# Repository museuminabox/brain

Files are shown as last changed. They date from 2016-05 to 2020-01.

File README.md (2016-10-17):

# brain

You're probably looking for https://github.com/museuminabox/brain/blob/master/INSTALL.md.

When you get your Museum in a Box, the box knows which objects are in it and can tell you things about them. That's because of The Brain, a microcomputer like a Raspberry Pi. There are a few peripherals too, like an RFID reader, speakers, and a screen. The brain also keeps a note of any time an object comes across it. This is called the BOOP LOG.

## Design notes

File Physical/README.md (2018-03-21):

# Physical Details of the Brain

This folder holds things relating to the physical instantiation of the Brain (rather than the software installed on it).

That includes things like the design files for laser-cut enclosures, and design files for [any custom PCB](BootProgressBoard/).

## Wiring

These wiring details use [this Raspberry Pi GPIO connector diagram](http://elinux.org/RPi_Low-level_peripherals#Model_A.2B.2C_B.2B_and_B2) for labels.

### RFID Reader

|Connector P1 (l-r)|Raspberry Pi|
|---|---|
|VCC|+3V3|
|IN|Not connected|
|SDA|GPIO2/SDA1|
|SCL|GPIO3/SCL1|
|OUT|GPIO4|
|GND|GND|

### BootProgressBoard

|Connector P1 (l-r)|Raspberry Pi|
|---|---|
|1|GPIO24|
|2|GPIO25|
|3|GPIO17|
|4|GPIO27|
|5|GPIO22|
|6|GPIO23|
|7|GPIO10|
|8|+3V3|
|9|GND|

### Raspberry Pi 2/3

Audio is provided by an amplifier board connected to the 3.5mm jack on the Pi.

See [here for a diagram showing the 3.5mm connections](http://www.raspberrypi-spy.co.uk/2014/07/raspberry-pi-model-b-3-5mm-audiovideo-jack/)

|Amp|3.5mm jack on the Pi|
|---|---|
|Left|Tip|
|Right|Ring 1|
|Ground|Ring 2|
|Not connected|Sleeve|

### Raspberry Pi Zero

Audio is provided by a DAC board.  Either the [Pimoroni pHat DAC](https://shop.pimoroni.com/products/phat-dac) with stackable headers; or the [Adafruit I2S DAC/Amp board](https://learn.adafruit.com/adafruit-max98357-i2s-class-d-mono-amp/overview).

For the DAC/Amp the connections are as follows:

|DAC/Amp board|Raspberry Pi|
|---|---|
|LRC|GPIO19/MISO|
|BCLK|GPIO18|
|DIN|SCLK/GPIO21|
|GAIN|Not connected|
|SD|Not connected|
|GND|GND|
|Vin|+5V|

Because the DACs don't have volume controls, we add two buttons for volume up and down.  They're connected as follows (l-r in [this photo](https://www.flickr.com/photos/amcewen/31221595945/)):

|Volume board|Raspberry Pi|
|---|---|
|Volume up|GPIO6|
|Volume down|GPIO13|
|Ground|GND|
|Pin with neither button but both resistors|Not connected|

## Assembly

This isn't necessarily the *only* way to assemble the Brain, but the general order that we've taken.

### Assemble "base of the skull"

1. Assemble an [audio circuit](#Wiring_the_audio_circuit)
1. Assemble an amp-to-speaker wiring loom
1. Carefully bend the terminals on the speaker so that they form a right-angle
1. Test assemble the speaker frame and then glue it together with the speaker inside
1. Plug in the 3.5mm audio jack to connect the audio circuit to the Raspberry Pi
1. Fit the rivets into the base first
1. Push Raspberry Pi down onto the rivets in the base

### Assemble "top of the skull"

1. Lay out all the components to check that you've got everything.
1. Insert the 4 t-nuts into the base of the top
1. Solder the right-angle header onto the RFID reader
1. Test assemble the RFID reader frame, and then glue together
1. Check the fit for the pieces making up the main box
1. Glue together the pieces for the main box, apart from the top
1. Once the main box is dry, glue in the top
1. Sand down the box (if it's not acrylic)
1. Apply one or two coats of Danish oil to the box (similarly if it's not acrylic)

### Wiring the Boot Progress PCB

1. Solder up the Boot Progress Board PCB

### Wiring the audio circuit

1. For the analogue amplifier Brains, solder header pins into the amplifier
1. We use pre-assembled [cables connected to a TRRS 4-pole 3.5mm jack plug](http://uk.farnell.com/cliff-electronic-components/fc68122c/cable-assembly-jack-plug-4-way/dp/2470995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) to connect to the Pi, so check that which wire colour goes to which pole on the plug.  If you're soldering your own wires to a 3.5mm plug, then obviously you'll know which is which.  In our case the colour-coding is:
  * Tip: red
  * Ring 1: white
  * Ring 2: black
  * Sleeve: shielding
  Or for the double-ended cables we're using in v1, the colour-coding is:
  * Tip: red
  * Ring 1: white
  * Ring 2: green
  * Sleeve: blue or black
1. Assuming you're using the same [3.5mm switched audio jack](http://www.digikey.co.uk/product-detail/en/cui-inc/SJ1-3535/CP1-3535-ND/738693) as we do, then connect the following connections to wire the 4-pole TRRS plug to the aux audio jack:
  * Tip (red) to connection 2
  * Ring 1 (white) to connection 3
  * Ring 2 (black/green) to connection 1
  * Sleeve is left unconnected
1. If you're using the same amplifier board as us, you should desolder the audio jack from it.  When you have, the connections&mdash;when viewed from underneath, from left to right&mdash;are tip \ sleeve / ring (on a TRS stereo jack)
1. Wire the output connections of the aux jack to the amplifier, with ~20cm of cable.  We'll leave the ground connection unconnected as it will prevent a ground loop with the ground connection for power.
  * Connection 4 (red) to the left audio input
  * Connection 5 (white) to the right audio input

### Prep the amp-to-speaker wiring loom

1. Cut a 15cm length of 2-core cable
1. Bare ~5mm of wire at one end and tin the end
1. Bare ~10mm of wire at the other end
1. Insert the longer bared ends through the loops on the terminals on the speaker (if you've got coloured wire, red to positive and black to negative) then fold it back on itself to make a decent physical connection.  Then solder the wires to the speaker terminal

### Assemble main wiring loom

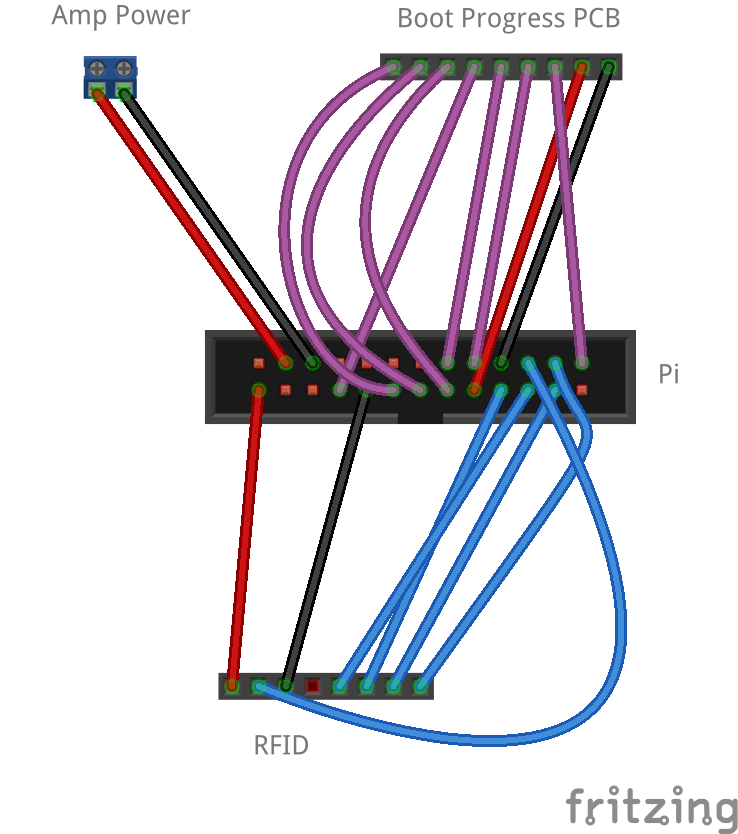
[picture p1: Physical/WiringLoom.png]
Image of wiring loom


1. Get the RFID to Pi connector cable
1. Wire a two-pin shroud to the 5V and ground connection on the RFID reader shroud to break out power from the Raspberry Pi to the amplifier
1. Assemble the Boot Progress PCB wiring loom with 9-pin shroud and [connections as detailed above](#BootProgressBoard)

### Assembly
1. Fasten the USB extension cable into the main box
1. Connect up all the electronics and make sure it's all working before it gets installed fully
1. Fit the amp and 3.5mm jack socket into the main box
1. Hot-glue the boot progress board into the main box

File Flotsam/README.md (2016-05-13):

# Flotsam

Handy bits and pieces that aren't crucial to the Brain or its operation, but are handy to have stashed away in source control.

## Files

 * [DisplayCard.docx](DisplayCard.docx) - a simple "what is this?" card to position next to the Museum in a Box if it's on display unattended somewhere.  Like the sort of thing that's next to an exhibit in a museum.  Works remarkably well just laser-printed and spray mounted to a piece of white foamcore.
 * [TagSizeTemplates.svg](TagSizeTemplates.svg) - laser-cutter outline file to cut a variety of common NFC tag sizes, so you can check them against prints to see what fits before you buy tags.

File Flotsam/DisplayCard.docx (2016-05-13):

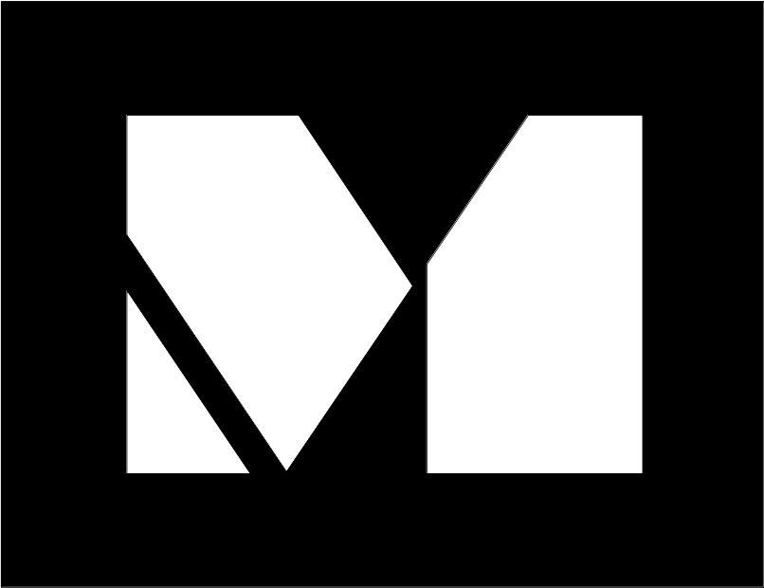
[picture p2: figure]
Created with Sketch.

Museum in a Box

http://www.museuminabox.org

3D scanned and 3D printed objects from museums, with some smarts inside.

Place an object onto the “brain” box to learn more...

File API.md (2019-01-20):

# Cloud API

These are the calls the box expects to be able to call in the cloud service, in order to administer the box.

Previously the paths did not start with `/api/`. The old URLs should now redirect to the new paths that do start with `/api/`.

## Record Boop Start

POST https://museuminabox.herokuapp.com/api/boopstart at the start of the Boop

NO LONGER WORKING: POST https://museuminabox.herokuapp.com/boops This is the old pre-v1 API to record (the start of) a Boop

### Submits

Example of a Boop submission currently:

JSON:
```
{ 
  "created_at": "2018-02-26T14:46:15.704Z", 
  "box_id": 64, 
  "print_id": "347"
}
```

 Yes, "print_id" appears to be sent as a string, so to support this, both IDs can be sent as integers or strings.
 
`box_id` can also be a Box's UUID - this should be the standard in the future. e.g.:

```
{ 
  "created_at": "2018-02-26T14:46:15.704Z", 
  "box_id": "1277209b-7e87-4023-a852-617e79ae6b18", 
  "print_id": "347"
}
```

### Success response

200 status code.

Returns the ID of the Boop that was created.

```
{
  "boop_id": 12345
}
```

### Error reponse 

400 status code (for example).

JSON returned will be like:

```
{
  "success": false,
  "errors": [
    "Something went wrong",
    "And here's another error message"
  ]
}
```

## Record Boop End

POST https://museuminabox.herokuapp.com/api/boopend at the end of the Boop

### Submits

JSON:
```
{ 
  "created_at": "2018-02-26T14:46:15.704Z", 
  "boop_id": 12345
}
```

### Success response

200 status code.

Returns the ID of the Boop that was updated.

```
{
  "boop_id": 12345
}
```

### Error reponse

400 status code (for example).

JSON returned will be like:

```
{
  "success": false,
  "errors": [
    "Something went wrong",
    "And here's another error message"
  ]
}
```

## Create box by UUID

POST http://museuminabox.herokuapp.com/api/boxes.json

### Submits

* UUID for the box to be created, as parameter `id`.
* The Hardware ID, as entered by the user. A string as parameter `hardware_id`.
* The box's exterior description. A string as parameter `exterior`.

### Success response

200 status code.

JSON of box details for the newly created box, as would be returned by the Retrieve box details API.

### Error response

400 status code (for example).

JSON returned will be like:

```
{
  "success": false,
  "errors": [
    "Something went wrong",
    "And here's another error message"
  ]
}
```
 
## Retrieve box details

GET http://museuminabox.herokuapp.com/api/boxes/:box_id.json

`box_id` can be the Box's database ID or its UUID (for newer boxes).

The JSON response will be something like:

```
{
  "id": "8e12b719-3c76-4a6a-9465-1087697acc61",
  "hardware_id": "0001",
  "exterior": "Shiny yellow plastic",
  "created_at": "2018-02-22T12:00:00Z",
  "updated_at": "2018-02-22T12:00:00Z",
  "brain_type": "audio",
  "private": True
}
```

## Synchronize box information for a given box

POST http://museuminabox.herokuapp.com/api/boxes/:box_uuid/sync.json
 
### Submits

JSON:
```
{ 
  "software_version": "0.9.0", 
}
```

### Success response

200 status code.

JSON:
```
{
  "prints": [
    {
      "id": 12,
      "name": "thing_name",
      "collection_id": 11,
      "collection_name": "Ancient Egypt: Daily Lives"
      "url": "https://museuminabox.herokuapp.com/boxes/12/",
      "brain_type": "audio",
      "image_url": "https://museuminabox.s3.amazonaws.com/prints/images/95e5e0bd-a724-4ba2-8004-a2abb92896a5.jpg",
      "brain_filename_audio": "b1bd2c2c-ce86-4360-a195-60a40353ac72.wav",
      "brain_url_audio": "https://museuminabox.s3.amazonaws.com/prints/audio/b1bd2c2c-ce86-4360-a195-60a40353ac72.wav"
     },
     {
      "id": "8e12b719-3c76-4a6a-9465-1087697acc61",
      "name": "thing_name",
      "collection_id": 110,
      "collection_name": "Barnsley Museums - Collections 1-6"
      "url": "https://museuminabox.herokuapp.com/boxes/34/",
      "brain_type": "audio",
      "image_url": "https://museuminabox.s3.amazonaws.com/prints/images/95e5e0bd-a724-4ba2-8004-a2abb92896a5.jpg",
      "brain_filename_audio": "b1bd2c2c-ce86-4360-a195-60a40353ac72.wav",
      "brain_url_audio": "https://museuminabox.s3.amazonaws.com/prints/audio/b1bd2c2c-ce86-4360-a195-60a40353ac72.wav"
    },
  ]
}
```

## Retrieve list of available boxes

DEPRECATED.  Used in the initial brain bootstrapping workflow, now superseded by the Create Box by UUID workflow.

GET http://museuminabox.herokuapp.com/api/boxes.json

### Returned

JSON:
```
[
  {
    "id": box_id, 
    "hardware_id": "The box hardware ID",
    "url": box_details_url,
    "name": "Name of the Box",
    "brain_type": "audio"  // LEGACY, used to be either "audio" or "video", currently "audio" is the only type supported
  },
  ...
]
```

`box_id` will be a UUID for boxes that have them, otherwise the internal numeric database ID.

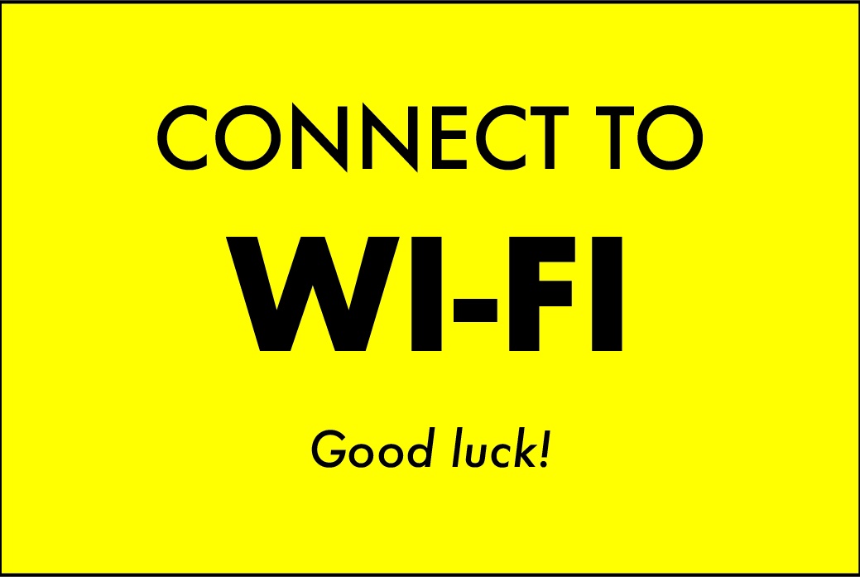
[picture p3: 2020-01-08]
miab/web-static/wifi-card.jpg

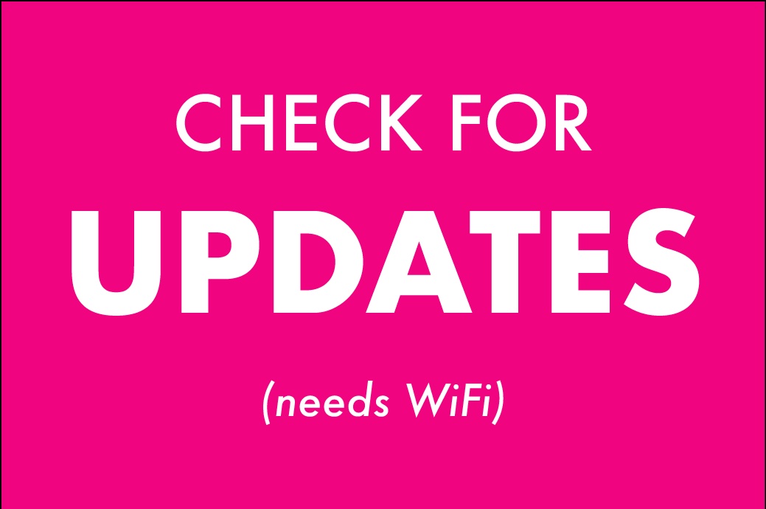
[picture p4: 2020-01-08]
miab/web-static/update-card.jpg

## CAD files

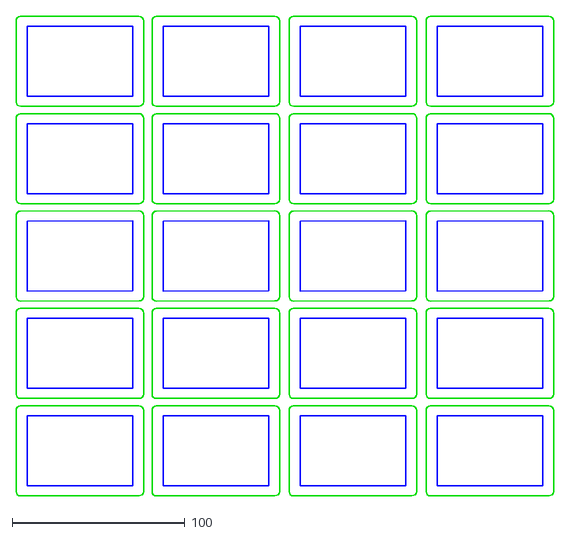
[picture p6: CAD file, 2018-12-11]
Physical/skull_20_reader_spacers.dxf
311.2 x 277.6

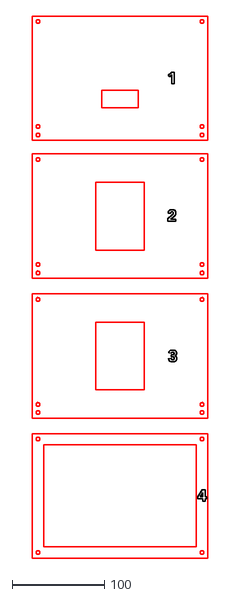
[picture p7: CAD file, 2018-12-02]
Physical/rfid_positioning_jig.dxf
190.0 x 587.8

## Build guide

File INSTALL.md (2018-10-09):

# Building a Brain

## Prerequisites

1. Raspberry Pi 2
1. SL030 RFID reader
1. SL030 to Raspberry Pi interconnect cable
1. Power supply
1. Speakers
1. Micro-SD card (8GB or higher recommended)
1. HDMI screen (for video version)
1. WiFi dongle (optional)

## Assembly

1. Attractively arrange componentry on a table - _this requires considerably more information :)_
1. Place micro-SD card into Raspberry Pi
1. Put WiFi dongle into one of the USB ports on the Raspberry Pi
1. Connect the short (6-way) end of the Pi-to-SL030 interconnect cable to the SL030 RFID reader.  The red wire should connect to the pin marked Vcc and the black wire should connect to the pin marked GND.
1. Connect the long end of the Pi-to-SL030 interconnect cable to the headers on the Raspberry Pi.  The wires should be in the "bottom left" of the headers if the Raspberry Pi logo printed on the Pi is the correct way round.
1. (Optional) Connect the HDMI cable if this is a video brain.
1. Connect the power to the Pi.

## Installation

### Manual Install

1. Install latest Raspbian
1. Install Node RED (if it wasn't already on the Raspbian image)
1. Install rfid-sl030 and ndef node.js modules
1. Copy contents of [miab](miab) to /home/pi
1. Copy flows_brain.json to /root/.node-red/ (you will need to rename it to flows_<hostname>.json depending on the hostname of your Pi)
1. Install [simple_sl030_rfid_reader]() and build `get_first_ndef_text_record` for it
1. Copy `bootprogress` to `/etc/init.d` to indicate progress during boot-up
1. Set `bootprogress` to run - `sudo update-rc.d bootprogress defaults`

### Ansible Install

1. Install [Ansible](https://www.ansible.com/get-started) on your computer
1. Install the latest [Raspbian lite image](https://www.raspberrypi.org/downloads/raspbian/) onto a micro-SD card
1. Create a file called `ssh` on the `/boot` partition of the SD card.  The contents don't matter, it's just to enable the SSH server.  E.g. on Ubuntu `touch /media/myusername/boot/ssh`
1. Boot the Raspberry Pi with the micro-SD card, while plugged into a network via Ethernet
1. Find out the IP address of the Raspberry Pi
1. Copy your SSH credentials onto the Pi
  ```ssh-copy-id pi@<ip-address-of-the-pi>```
1. Edit the ```hosts``` file so ansible knows which computer to configure.  Change the IP address in it to match the one you just found out.
1. Check you can run commands on the Pi using Ansible
   ```ansible brain -i hosts -a "hostname" -u pi```
1. Create a password for the `pi` user
   ```mkpasswd --method=sha-512 > pwd.txt```
1. Update the brain
   ```ansible-playbook brain.yml -e pi_password=`cat pwd.txt` -i hosts```

### Pre-rolled Image Install

Or use the pre-rolled images...

1. Download one of our image files
1. Unzip it, so you end up with a brain-YYYYMMDD.img file
1. Write the .img file to the SD card, following the steps on the Raspberry Pi website - [Mac](https://www.raspberrypi.org/documentation/installation/installing-images/mac.md)/[Windows](https://www.raspberrypi.org/documentation/installation/installing-images/windows.md)/[Linux](https://www.raspberrypi.org/documentation/installation/installing-images/linux.md)
1. Put the SD card into the Raspberry Pi on the Brain and boot it up
1. Visit [http://box.local:1880/setup](http://box.local:1880/setup) to configure the brain

## Connecting to WiFi

To add new WiFi network credentials to the brain you will need a working network connection to the brain already.  So either add the settings before you move it from a known WiFi setup, or connect it to the network via Ethernet first.

 1. Get a command line connection to the brain ssh pi@brain-1.local
    - turn on pi, plug ethernet
    - (optional, for direct to laptop) share wifi via ethernet, set IP Add. to 10.0.0.1, make sure wifi is connected!
    - in terminal, type ssh pi@brain-1.local (or pi@brain-2..., or pi@brain-3...)
    - enter password for brain
 1. Run the WiFi config console
     sudo wicd-curses
 1. Find the network that you want to configure on the list.  Press the -> key to move to the configuration screen.  Use the down cursor key to find the "Automatically connect to this network" setting, then press the space bar to enable it "[X]" rather than "[ ]".  If the network requires encryption then cursor down to the "Key:" field and fill in the password there.
 1. Hit "F10" to save the settings.
 1. Type "Q" to quit from the WiFi config app.
 1. Next time you boot up, it should choose the newly configured WiFi.  (You'll need to unplug the Ethernet if you've used that, otherwise it'll use that in preference)

## Writing new tags

### Writing the metadata to the tags
1. Get the system up and running
1. Using an NFC-enabled phone, write a URL to the tag you want to write. (It will be overwritten, and this step will be removed when we work out how to format blank tags)
1. Place the tag onto the reader
1. In a browser, go to http://brain-1.local:1880/tag (depending on which brain you're connecting to, it might be brain-2.local instead)
1. Fill in the details
  * URL is the link to the print on the website (this is where a Phone will visit when you tap the tag on it)
  * ID is the print's ID in the database (the number at the end of the URL)
  * The filenames are the names of the media files that you'll copy onto the Brain in a minute
1. Click write

### Copying content over to the Brain
1. Open the "transmit" app (on Mac)
1. Create a new favourite, with the server of box.local, protocol set to "SFTP" username pi, password raspberry
1. Connect to it, copy the audio and video files into the respective miab/audio and miab/video folders
1. Repeat the process for all the other brains

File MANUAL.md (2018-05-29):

# Museum in a Box User Manual

## Configuring Wifi

Although your Museum in a Box will work just fine, to receive automatic updates to the content; check for updates; or let us discover which objects are the most popular requires a connection to the Internet.

The Box connects to the Internet over wifi, so you will need to tell the Box the details for your wifi network:

  1. Boop the `Configure Wifi` tag onto the box
  1. That will create a `MuseumInABox` wifi network.  Connect to  that with your phone or laptop
  1. Usually that will automatically open this page which will let you enter the details for the network that the Box should use to connect to the Internet.  If this page fails to open, then visit [http://box.local/](http://box.local) (or if that fails to load, then [http://192.168.42.1](http://192.168.42.1)) in a web browser

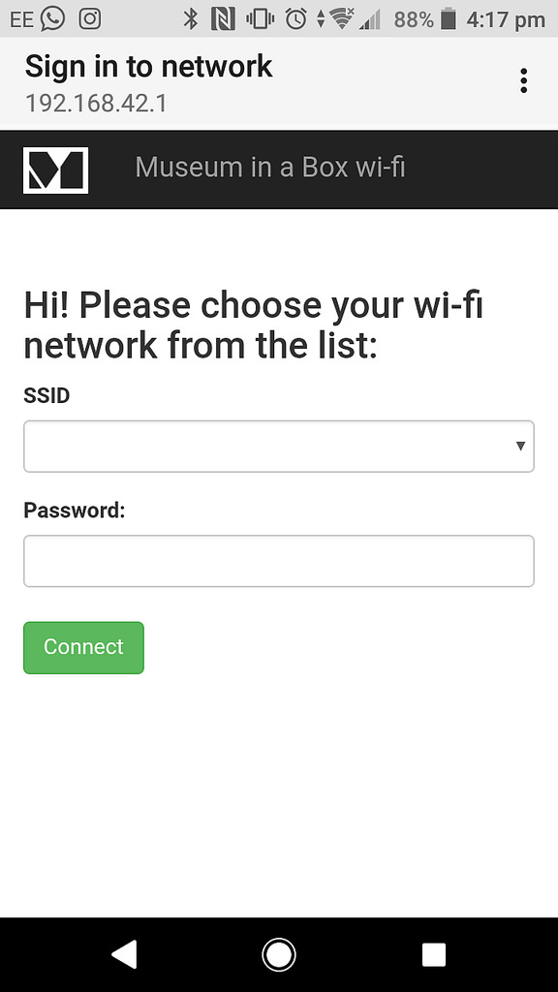
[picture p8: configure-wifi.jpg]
  

You will then be disconnected from the `MuseumInABox` network while the Box tries to connect using its new settings.  It will then tell you whether or not it succeeded.

### Advanced Wifi Options

We now have initial support for hidden and WPA Enterprise (also known as 802.1x) wifi networks.  To configure your Box to use one of these networks then follow these steps rather than those above.

  1. Boop the `Configure Wifi` tag onto the box
  1. That will create a `MuseumInABox` wifi network.  Connect to  that with your phone or laptop
  1. Ignore the standard configure wifi screen.  Instead, open a web browser and go to [http://box.local:1880/wifi](http://box.local:1880/wifi) (or if that doesn't load, then [http://192.168.42.1:1880/wifi](http://192.168.42.1:1880/wifi))
  1. That will present you with the following screen.  Enter the details for the particular type of network that the Box should use to connect to the Internet and then hit `Save`

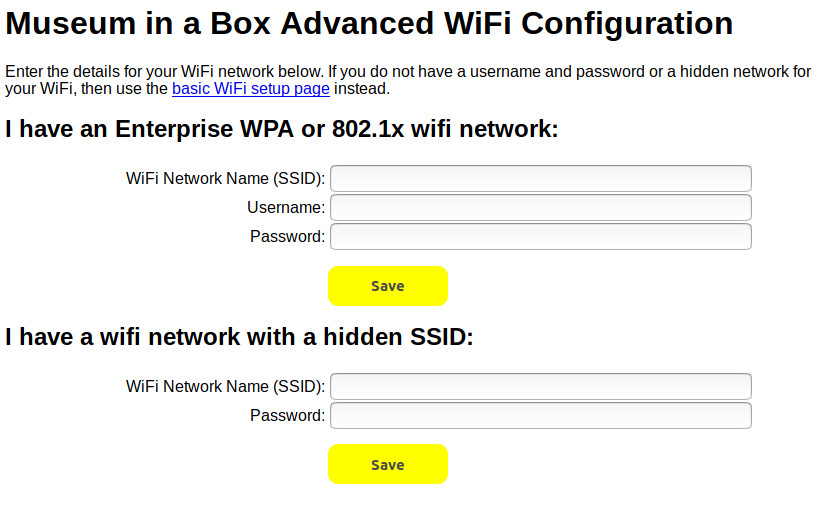
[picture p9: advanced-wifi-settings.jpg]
  

You will then be disconnected from the `MuseumInABox` network while the Box tries to connect using its new settings.  It will then tell you whether or not it succeeded.

## Checking for upgrades

Occasionally there will be software updates available for your Museum in a Box.  Generally, the team at Museum in a Box HQ will let you know if there's something available.

When you want to check for, or apply, an update the process is quite simple:

  1. Make sure your box is connected to the Internet.  Follow the steps to [Configure Wifi](#configuring-wifi)  if you haven't already done so
  1. Boop the `Check for Updates` tag onto the box
  1. The box will then tell you that it is checking for updates.  Once any updates have been applied, it will tell you that everything is up-to-date

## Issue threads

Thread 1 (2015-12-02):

Log Boops

amcewen, 2015-12-02:
Relies on https://github.com/museuminabox/museuminabox/issues/9 being fixed to provide the API endpoint, but we should log each Boop on the server, and also log it locally to a file or similar (to allow us to track Boops even when offline)

amcewen, 2016-02-27:
We got this working for the first demo at the British Museum.

Closed 2016-02-27.

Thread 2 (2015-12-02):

Build cases for the RFID readers

amcewen, 2015-12-02:
Design and laser-cut cases for the RFID readers.  At least two:
 * 1x RFID reader enclosure with M-logo cutout
 * 1x RFID reader enclosure with M-logo engraved

amcewen, 2016-03-21:
This was done in time for our December launch event.

Closed 2016-03-21.

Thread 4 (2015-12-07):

Make sweet boop sound(s) happen quickly

george08, 2015-12-07:

george08, 2016-03-17:
I don't think the checkout noise is good anymore. Having connected the brain to good quality speakers today, I think it's an interruption rather than anything useful.

I've watched lots of people try their first boop though, and there's always a brilliant joy when the sound comes out. One person even blushed hugely when the Russian choir started singing. It was amazing.

Closed 2016-03-17.

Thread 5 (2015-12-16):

Need a way to control volume

george08, 2015-12-16:
Particularly on the laser cut box from Dec 8.

amcewen, 2015-12-24:
Just a quick update - haven't been able to create a fix for this yet as the spare (super cheap) microSD cards are all dodgy and won't work in the R.Pi.

Have ordered some better (I hope) replacements, so will get it sorted once they arrive (in the new year if not next week)

amcewen, 2016-01-13:
Okay, have got a working version now, and have worked up a not-perfect-but-hopefully-good-enough fix.

If you go to the control panel for the brain you want to change the volume for - the http://brain-1.local:1880/ URL for example - then you can add this to give you a functional volume control...

Copy the following chunk of JSON to your clipboard:

[{"id":"b69a4894.a22d5","type":"inject","name":"Full (400)","topic":"","payload":"400","payloadType":"string","repeat":"","crontab":"","once":false,"x":154.44444444444443,"y":541.1111111111111,"z":"8c018666.713f4","wires":[["4a5bc959.0e1758"]]},{"id":"3979d3a8.6b0134","type":"inject","name":"Off (-10239)","topic":"","payload":"-10239","payloadType":"string","repeat":"","crontab":"","once":false,"x":146.66668701171875,"y":586.6666870117188,"z":"8c018666.713f4","wires":[["4a5bc959.0e1758"]]},{"id":"3f4a2166.0600c6","type":"inject","name":"","topic":"","payload":"-500","payloadType":"string","repeat":"","crontab":"","once":false,"x":154.44444444444443,"y":637.7777777777777,"z":"8c018666.713f4","wires":[["4a5bc959.0e1758"]]},{"id":"4a5bc959.0e1758","type":"exec","command":"amixer cset numid=1 -- ","addpay":true,"append":"","useSpawn":"","name":"set volume","x":361.1111111111111,"y":580,"z":"8c018666.713f4","wires":[[],[],[]]}]

Then click the burger menu in the top right corner of the control panel, choose Import, then Clipboard.  Paste the JSON into the Import Nodes dialog box and click OK.

That will give you four new nodes - one labelled "set volume" and three others with different volume options.  Clicking the "Deploy" button in the top right corner will save those nodes so you can use them (and so they'll be there next time you boot up too)

Clicking on the little rounded-corner square button to the left of one of the options will set the volume to that level.  If you want a different volume level then double-click on one of them, type a different number into the payload (below the drop-down that says "string"), and then "Ok" and "Deploy".  The volume level can be anything between -10239 and 400 (such easy-to-remember values, no?!?)

I think you'll need to set it each time you boot, sadly, but I can work on something better next time I'm down.

amcewen, 2016-06-15:
We've now got hardware volume controls on the built-in amplifier

Closed 2016-06-15.

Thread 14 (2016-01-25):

What extra controls/output options do we need on the brain?

amcewen, 2016-01-25:
Particularly for the initial commission box, we should think about any extra controls needed.

What might go wrong?  What might we want to easily change?  What run things could we include?
- Volume control - ideally a knob, but could cope with up/down buttons
- A mute button
- An "online support" button/switch?  That would create an ssh tunnel to our server so we can log into it remotely to do debugging.  Button that would just enable it for a set time period, switch would let you control when it was on/off

For error messages, we can play back audio for them.  Do we also want any indicator LEDs, etc?

amcewen, 2016-01-25:
On/off button?  Powered on LED?

amcewen, 2017-02-15:
We have a load of indicator LEDs now, so I think this is good to close.

Closed 2017-02-15.

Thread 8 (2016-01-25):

How do boxes connect to the WiFi?

amcewen, 2016-01-25:
What's the best way for the boxes to connect to the network?

Possible options include (but aren't limited to...):
- Use NFC network details standard and the RFID reader
- As above, but with an NFC rather than RFID reader on the boxes (so needs different hardware to the prototypes), and would let Android users transfer the details straight over without an intermediary NFC tag
- Create its own WiFi network and let people connect to that and configure it - see the BBC R&D work on Radio Dan
- Write details to a USB stick or the SD card on the Brain (@amcewen did that on http://russelldavies.typepad.com/planning/2011/07/secondary-attention-and-the-background-noise.html)
- A phone app?  The ESP8266 boards have a phone app to make configuring it easier - I don't know how that works, but should find out (and will be, as part of the work I'm doing on https://github.com/mcqn/cocklecraft-of-things)

amcewen, 2016-01-25:
At present the WiFi settings all get stored in /etc/wicd/wireless-settings.conf

amcewen, 2017-09-13:
I've built a test version which uses the Resin.io https://github.com/resin-io/resin-wifi-connect.  Getting it to work required modifying src/hotspot.js to shutdown dnsmasq before the hotspot started.  Current w-i-p stored in the branch feature/8-configurable-wifi.

If it works, it will need (at a minimum) the ansible scripts finishing, and also the mod to shutdown dnsmasq to be implemented properly (check if dnsmasq is running before stopping it, and restarting it when the hotspot is disabled)

amcewen, 2018-11-15:
This has been working okay now, and the remaining issues have been raised as #79 and #78, so closing this.

Closed 2018-11-15.

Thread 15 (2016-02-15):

Play a tune when the brain is ready to accept objects

amcewen, 2016-02-15:
Have some sort of indication that all the software is up and ready for you to place objects onto it.

amcewen, 2016-04-11:
Fixed with the latest flows_brain.json, checked in for https://github.com/museuminabox/brain/commit/f0f600cdddf77ff0a0098bbe74680c8c7172c219

However, the ready.wav needs to be checked into git.

amcewen, 2016-06-15:
ready.wav is now in github too.  (And we have a big green LED that lights up too, now)

Closed 2016-06-15.

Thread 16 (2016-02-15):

Indicate that the box is powered on asap

amcewen, 2016-02-15:
When the box is turned on, it'd be good to get some feedback to the user as quickly as possible - either an LED or a sound or similar...

amcewen, 2016-06-15:
With the latest laser-cut boxes we now have an LED that comes on as soon as power is provided, and then more that come on as boot up proceeds

Closed 2016-06-15.

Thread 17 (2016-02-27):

Make it easier to provision a new brain

amcewen, 2016-02-27:
In concert with the work in issue #10, we'd like an easier way to bootstrap a brain.

The workflow will be as follows:

 * Once the brain software is installed, visit http://brain-ip-address:1880/setup
   * That pulls a list of boxes from museuminabox.org
   * Shows the list of boxes for you to choose from.
 * When the box is selected, it will save the relevant config for the brain (hostname, config in Node-RED so that Boops are correctly recorded, etc.)
 * The initial syncing of content (unless issue #10 renders a specific initial sync unnecessary) should be kicked off
 * Then you'll be redirected to http://brain-ip-address:1880/prints
   * That will show a list of prints, with a "write tag" button next to each one.
   * Clicking the "write tag" button will write the relevant info to the NFC tag

george08, 2016-03-17:
I find myself wanting this more and more @amcewen. I've had a good few days (finally) to work on content stuff. Not just for The First Commission, but wanting to whip up things quickly, like The World's Smallest Hans Sloane Collection. :)

Do you think we could try to organise a day or two to concentrate on this one?

amcewen, 2016-09-22:
From the merge comment of branch "Feature/17 easier provisioning":

In lieu of knowing how to better streamline the whole provisioning a box process (writing tags, etc.), this fixes issue #17 (and we can open more specific bugs once/if we have a better process in mind).

Closed 2016-09-22.

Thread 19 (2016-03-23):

How do we update the software for a Brain?

amcewen, 2016-03-23:
There are an assortment of dependencies for a Brain - Node RED, the RFID code, the Node-RED flow, etc.

It will make life much easier if there's a simple way to push updates out to the various brains, even just for the different MiaB offices, and longer-term as they venture out into the wild...

amcewen, 2016-03-25:
Hmm, plenty of options for ways to do this, and no obvious one to pick.

 * Puppet
 * Chef
 * Docker
 * Ubuntu Core
 * Resin.io
 * Canned .img files
 * Ansible

## Puppet
 + Available in Raspbian. - I haven't used it before. - Generally requires a central server to provision things (not an issue long term, but not sure we need that right now)

## [Docker](https://www.docker.com/)
- Not available in Raspbian, but can be installed in Ubuntu Core and Resin.io.  - Few, if any, pre-rolled containers for ARM (the processor in the Pi).  + I'm already using it for mcqn.com, so there's no learning curve

## [Ansible](https://www.ansible.com/)
- Seems more tailored to inter-dependent server deployments.  - Not available in Raspbian.  - I haven't used it before.

## [Chef](https://www.chef.io/)
+ Available in Raspbian.  + Can run without a central, controlling server.  - I haven't used it before

## [Ubuntu Core](https://developer.ubuntu.com/en/snappy/start/raspberry-pi-2/)
+ Designed to solve this sort of problem.  + Available for Raspberry Pi 2 and above.  - Not available for Raspberry Pi 1 or Pi Zero.  + Allows easy rollback to earlier versions if there are problems with a new version.

## [Resin.io](https://resin.io/)
+ Designed to solve this sort of problem.  + Works on all Raspberry Pi models.  - Based on Yocto Linux (which I've not used much).  - $60/month once you've got more than 5 devices (and more as you grow).  + Uses Docker containers (although that will hit the same issues with a lack of pre-rolled containers).

## Canned .img files
+ Simplest option.  - Hard to track changes in source control.  - Difficult to upgrade systems once deployed (well, just as simple as initial install, but rather scorched earth about it, and can't be done remotely).

infovore, 2016-04-04:
Just as a heads-up - I found Ansible much more straightforward for provisioning tiny, single things, than Chef Solo ever seemed to be: Chef Solo always felt like it was cut down from something large, wheras with Ansible, you can start with a single file with few dependencies; it's definitely not tailored to a particular shape of work.

The big question is how much can you rely on staying the same: if you can constrain changes to being in application code, rather than system-level, it becomes easier to push out changes to an application. Wheras if it's a moving target and you want to re-provision the entire system regularly... that becomes more challenging, I guess. But it might help simplify the requirements of provisioning if the goal isn't to reflash an entire image every time.

It might also be worth thinking about the push/pull model - you say 'push updates', but really, the model feels like it might be more 'make boxes aware there's an update to pull / box sets about acquiring said update'. (And: might be worth notifying people of the ideal bandwidth required)

There's also something something about user notification - how is someone made aware their box is updating and they should probably not touch it? (The answer might be 'emailing them at some point', there's clearly a tonne of conversations I don't know about).

amcewen, 2016-04-04:
Good to get some actually-tried-it thoughts on Ansible/Chef, thanks!

And the rest of your comments are spot on too.  I think part of the problem is the tension between us having lots more experimentation to do and having our first commission, which is leading me towards wanting in-field updates and a good user experience.

Ubuntu Core has a mirrored file system, so installs the new version into an alternate partition and only switches to it when it's ready to run.  Which is a nice approach.  I don't know how well it does at resuming downloads/install if interrupted.

amcewen, 2016-10-04:
Changed the title because we've got the initial install stuff as part of the fix for #17, but we don't currently have a strategy for updating the software once it's out in the wild.

amcewen, 2018-11-15:
I think the updating fixes will be covered in #55, so closing this now.

Closed 2018-11-15.

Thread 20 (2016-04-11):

Reduce the lag between presenting a tag and hearing sound

amcewen, 2016-04-11:
There's an ~3 second gap between you presenting an object and having audio come out of the speakers.  This is mostly the time taken to read the tag, and needs to be as quick as possible.

Things to investigate:
 * Parsing the NDEF data as we go and stopping as soon as we've read it all (it currently reads in the whole tag, and then parses it for NDEF data
 * Rewriting the RFID reading and NDEF parsing code in C/C++
 * Trying the different NFC reader that I've got, in case that's faster (would also be using libnfc, which is more generalised for future expansion/compatibility, and more of it is written in C++ already)
 * Something else we've not thought of yet...

george08, 2016-04-29:
I'd call this more a need than an enhancement. It's confusing to people when we show it to them. The first instinct is 'oh, this isn't working, i'll take it off' and that's just when the playing starts, and then you get this jerky thing.

Ideally, this interaction would be as close to instant as we can get it.

amcewen, 2016-09-22:
The commits https://github.com/museuminabox/brain/commit/01a1ac044c24c39f1d568b86c270b40b60583300 and https://github.com/museuminabox/brain/commit/8dc74b3595eda0c12a7e9d801469db1d0e8a33a9 made this much better.

Closed 2016-09-22.

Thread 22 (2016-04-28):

Filenames with special characters

nebulousflynn, 2016-04-28:
Just a note to say that there are some inconsitencies between S3 file names and the URLs it serves up i.e.:

URL from S3 / written to tag:   Adam+%26+The+Ants+-+Prince+Charming.wav
File loaded onto pi:                  Adam+&+The+Ants+-+Prince+Charming

I fixed this by renaming the file via FTP to include %26 instead of &.

Brackets seem break things entirely - not necessarily an issue with code as could be fixed by naming things differently as they are uploaded to S3

george08, 2018-11-15:
Is this still an issue?

Closed 2018-11-15.

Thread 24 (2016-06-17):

Boop logging is hard-coded to box 2

amcewen, 2016-06-17:
When I updated the NodeRED flow to add the "configure this to brain X" I missed the part where boops are logged, so at present all claim to have been booped on Brain 2 (because that was the one the base for the newer flow was configured for).

Should be a fairly simple fix, once I get a working brain here to check it with.

amcewen, 2016-09-22:
The flow was updated as part of the fix in #29.

Closed 2016-09-22.

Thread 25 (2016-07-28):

Timed LEDs take too long to light up

nebulousflynn, 2016-07-28:
the Brain start up time is so fast now (good thing) that the timed LEDs light up slower than they should i.e. the Big Green LED lights up before all the orange ones have finished turning on

amcewen, 2016-08-02:
If you've got a box with LEDs to hand (I've not just at the moment, but will get one at some point) it'd be good to time how long it takes to (a) get to the first yellow LED and (b) to the green LED.  I'll do a couple of tests with the Pi3 and see if that's any faster too, and we can settle on the shortest time for them...

Closed 2017-03-27.

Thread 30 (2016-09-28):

Tidy up micro:bit integration

amcewen, 2016-09-28:
We need the Brain to work out what things to send to the micro:bit so that we can relay metadata over to other micro:bits.

At present it sends "y<year>" and "p<place>" packets, followed by an "f" packet, for each boop.  They should just be sent as separate lines of text to the serial port, at 115200 baud.  Once we know what metadata to send, we might need to extend things, both in the flow and in the microbit-miab code.

george08, 2018-08-08:
This is far from a priority.

Closed 2018-08-08.

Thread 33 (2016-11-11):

Problems writing / overwriting tags

nebulousflynn, 2016-11-11:
Having trouble writing tags for the I See Wonder brain - possible long audio file names?

Problems with prints IDs 176, 177, 178.

i.e. https://s3-eu-west-1.amazonaws.com/miab-brain-content/audio/i_see_wonder/astronomy/7-Schematic-of-Saturns-rings-from-Cristiani-Hugenii-Zulichemii.wav

amcewen, 2017-01-17:
It's a size problem (as we worked out a while back).  Trying to write too much data to the tag can corrupt the tag.

I've updated the Node RED rfid nodes so they check the size of the tags (for any of the NTAG2xx classes of tags) in https://github.com/mcqn/node-red-contrib-nfc/commit/5f55bfc69dd018f389714957e469002435c658c6 which **mostly** fixes the problem.

The bit it doesn't fix is telling you that it hasn't written the tag.  You just won't get the "OK" message.  I had a look at fixing that, but couldn't find how to catch the error and pass that through :-/  The error shows up in the debug console of the Node RED screen, but not through to the Javascript showing the status next to the button.

Looking at it more now, I haven't quite done enough in the rfid nodes to communicate the error.  I'll pick it up from http://nodered.org/docs/creating-nodes/node-js#handling-errors when I'm next working on this.

nebulousflynn, 2017-01-18:
thanks for info @amcewen - wondering if we could also limit char length for input fields in Admin to prevent this too

amcewen, 2018-04-14:
I've worked out how to improve the error reporting through this, so it now gets passed to the `/prints` page as well as reported  in the debug console (so you see more quickly on the `/prints` page rather than having to wait for the AJAX call to time out).

Closed 2018-04-14.

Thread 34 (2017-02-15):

Turning the volume off/on tends to reboot the Pi

amcewen, 2017-02-15:
On the Brains with analogue audio, the small amp board we're using has an on/off switch at the limit of its volume control.

It's not useful, as it doesn't affect the rest of the Pi's power control, so it's not necessary to keep the functionality.  However, it seems to spike the power (or draws too much?) when you turn it off and then on, which results in the Pi rebooting.

amcewen, 2017-03-27:
@CharlieMiab's pin and knob design does a nice job of preventing the volume control from reaching its limit, and so fixes this nicely.

Closed 2017-03-27.

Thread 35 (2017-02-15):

Noise from Pi activity on the audio channel

amcewen, 2017-02-15:
The Brains with analogue audio often have some noise on the audio output, particularly when the Pi is active (it seems to synchronize with the disk activity LED on the Pi, for example).

amcewen, 2017-05-12:
Removing the ground connection on the audio connection, to avoid ground loops made little difference.  Ferrite beads on the audio lines similarly didn't help much.

So, ideally having an i2s DAC and amp (like the Pi Zero box) but with a rotary volume control is what we're after.  And more powerful than our current set up.

Some options (not verified that they'll all work with a Pi)...

DACs:
 * https://www.aliexpress.com/item/UDA1380-Board-UDA-1380-Module-Stereo-Audio-Codecs-Decoder-Based-on-I2S-Interface/548266169.html $9.99, has input as well as output
 * http://store.digilentinc.com/pmod-i2s-stereo-audio-output/ $13.99

Amps:
 * https://www.aliexpress.com/item/1PCS-YDA138-DC5-8V-Mono-12W-Amplifier-Board-Class-D-replace-PAM8403/32762847981.html $5.80 mono
 * https://www.aliexpress.com/item/LM386-Super-mini-amplifier-board-low-power-consumption-3-12V-Cost-performance-is-better-than-that/32664972721.html $2.19 through-hole, need to assemble ourselves
 * https://www.aliexpress.com/item/DIY-suite-DC-2-12V-TDA2822-Double-audio-power-amplifier-board-suite-DIY-TDA2822-Dual-channel/32662250547.html $8.78 through-hole, need to assemble ourselves
 * http://www.ebay.co.uk/itm/-/151862056655?var=451055165479 (our current amp module)

There's also the Voice HAT that came in the Google AIY kit, but it's not clear if that will be on sale separately at all

amcewen, 2017-10-11:
Switching to the PAM8403 amp (first option in the "Amps" section above) has sorted the noise problem nicely, so that's become our default option.

Closed 2017-10-11.

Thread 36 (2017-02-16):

Better power on/off options for Brains

amcewen, 2017-02-16:
At present there's no way to easily perform a clean shutdown of the brains, we just yank the power from under it.

We should try out the "RUN" two-pin connector on the newer (i.e. not original) Pi models to see if that works for it.

amcewen, 2017-02-18:
I've tried the RUN connector, which functions really well as a reset button, but doesn't power down (well, it does, but immediately boots up again...).

We could monitor a GPIO to have a "shutdown button" (i.e. watch for the GPIO pin being pulled high or low (whichever we prefer) and issue the shutdown command), but that wouldn't then work to restart things after it shut down :-/

By that point we'd probably be better off looking at some of the 3rd-party power switch boards, but that feels like something to revisit after v1.

Closed 2017-02-18.

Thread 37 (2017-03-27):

Boot progress PCB improvements

amcewen, 2017-03-27:
It'd be useful for the custom PCB to have some M3 mounting holes so we can mount it into the skull more easily.

amcewen, 2017-03-28:
We should also add the logo and URL to the bottom silkscreen.  And round off the corners of the PCB.

george08, 2018-02-15:
Can @CharlieMiab help with this? (Don't think we need it for Smithsonian phase?)

amcewen, 2018-03-07:
These changes were done in September https://github.com/museuminabox/brain/commit/c4a0ac8ae2831fba93a58347b327d153053245c1

And we've already had a bunch of the boards fabbed (they're what we're into using now).  I'd just missed out tying the commit back to this issue.

Closed 2018-03-07.

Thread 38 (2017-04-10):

Occasional problems writing tags

amcewen, 2017-04-10:
Discovered when we were writing the tags for box 53.  Some of the tags didn't seem to work, and in testing I spotted that one - for print 223 - when written from blank (in case that's important) managed to write "2...." into the text NDEF record, where the '.' characters are NULs (i.e. 0).

Rewriting the tag worked, and annoyingly I hadn't made a proper note of it to see whether it was definitely 4 NULs, but I'm pretty sure it was as there was no "," in the JSON that _should_ have read `"223","audio"...`

amcewen, 2018-06-05:
Pretty sure this was a duplicate of #33.

Closed 2018-06-05.

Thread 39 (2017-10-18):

Unpredictable/occasional restarting issues

amcewen, 2017-10-18:
Sometimes the Brain will reboot while powering up, at times repeatedly.  @george08 recorded the problem with one of the Brains being demoed/used on Monday.

It seems to be power-related.  I've seen it happen if using a thin USB cable rather than one of the better-specced USB power supplies (either the 5V 2A ones I've been buying from Farnell, or the 5.1V 2.5A official Raspberry Pi supplies).  Possibly also a problem when battery packs are running low or if lower-powered phone chargers are used.

amcewen, 2017-10-18:
When I've noticed it, it seems to happen around the time that the "one moment please" boot message is played.  I wonder if that's because it causes more power draw through the amp then?

george08, 2017-10-18:
Each restart on Monday happened *just* before it got to the green light. It would go back to the start, with the left-most light on. I don't think it replayed the "one moment please".

george08, 2018-11-15:
Let's close this one year old bug. Can reopen or recreate if we can reproduce.

Closed 2018-11-15.

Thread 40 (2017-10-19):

Boop log feature requests

george08, 2017-10-19:
- can it log the duration of the object on the reader?
- can it cross-reference that to the length of the audio for that object?

We're wondering if we could reveal if there was a playback bug this way... i.e. if the object was still on the reader, but the audio track stopped at a duration that's different from the expected one. Ie, if the track was 60 seconds, but the playback stopped at 10 seconds, and the object was still on the brain.

We've also been chatting about having a basic recorder in the system. Something to help us measure how much people react to the stuff. What if the recorder could measure a basic decibel level in conjunction with the object being placed on the reader. (So you might roughly perceive a group laughing or talking etc)...

george08, 2018-02-22:
Some visual sketches:

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

george08, 2018-02-28:
@amcewen just chatting with phil about what we can possibly squeeze out of him in the remaining days until Friday... i'm wondering if it'd be possible to send a bit more data about a boop between now and then? if we could bash out something super rough along the lines above, that would be very exciting! (past boops notwithstanding :) )

amcewen, 2018-02-28:
We could fairly easily add a(n optional, to continue to support boops from old brains) duration parameter, and have the boop be recorded when the object is removed (rather than when it's placed on the reader, as at present).

That should be reasonably easy for me to change the brains to support.  The only downside would be that you wouldn't see the boop happen while the object is on the brain (if there's a live update of the boop log on the heart site), it'd be just after.

Otherwise we'd have to have "boop on" and "boop off" APIs.  That's, if anything, slightly easier for me to implement, and slightly harder for Phil, but there's little in it.

Having the brain understand the duration of a boop and report it feels a bit cleaner than inferring it server side, but I'm not hung up on that if we'd rather have the option of a nicer "live" view in the future.

george08, 2018-02-28:
boop on + boop off sounds best to me. most accurate, most manipulable.

george08, 2018-03-01:
Can you please implement that?

The reason I'm asking for it to be done soon (now?) is because the Smithsonian grant we've won is a baby version of a much bigger possible grant - maybe six figures - and therefore our and SI's evaluation of the baby grant is really important. For us to be able to demonstrate _literal usage_ would be huge.

Phil had a great idea yesterday too, where you could actually _replay_ a session that actually happened by processing the boop log and knowing which tracks it refers to, playing/stopping them just like the kids did. Wouldn't that be amazing?!?!

george08, 2018-03-02:
Can we show a filtered list of boops here?
https://museuminabox.herokuapp.com/backstage/boxes/box/62/change/

(It's practically impossible to tell which brain is which with the data we have in the Django app.)

amcewen, 2018-03-21:
We've seen boops with a duration showing up in `heart`, so this has now been tested as well as implemented.

Closed 2018-03-21.

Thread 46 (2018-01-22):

Do everything in your power to reduce the file size of the new Wifi image

george08, 2018-01-22:
8GB seems like a lot! (And, would also mean we'll have to get 16GB SD cards as a minimum in future, so BOM would have to change.)

amcewen, 2018-01-24:
Does writing to an 8GB card not work?  The expanded img files end up that big because that's how big the SD cards I'm using are - they're not 8GB of /used/ space, just 8GB because it's a copy of a the entire card.

george08, 2018-01-24:
@CharlieMiab, your attention, please!

CharlieMiab, 2018-01-24:
No, Etcher refuses to let a 8GB card be written to even if the card has been wiped because the unzipped file still shows up as 8.02GB

amcewen, 2018-02-20:
We worked out that this was because not all SD cards are created equal :-/

Specifically, some 8GB cards are slightly bigger than others, and so if I create an img file from a bigger one, it can't be written to the smaller ones.  So, I need to make sure I build the "blank base img" files on the smaller cards.

Rjevski, 2019-11-13:
This is becoming an issue again as we need to write a lot of images and writing the full 8GB (most of which is free space) is wasteful.

I've looked at https://github.com/Drewsif/PiShrink and successfully ran it in an Ubuntu 18.04.3 VM; however I have not had the opportunity to test the new image to see if it resizes itself back to the proper size on first boot.

@CharlieMiab has the resulting image and is going to test tomorrow as per my instructions (etch the image, boot a box, SSH into it and run `df -h` to see if the partition is the proper size).

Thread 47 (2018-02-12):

Photograph complete exploded view of Brain/Skull version 1.0

george08, 2018-02-12:
I think this would be excellent documentation, not only for us to capture where we're at now, but also possibly prep/background materials for Make Your Own down the line.

We could blog the crap out of it, and make cool GIFs for the kidz.

CharlieMiab, 2018-02-20:
Will get cracking on this once we have received all the ordered parts.

george08, 2018-12-14:
Missed our chance on this :)

Closed 2018-12-14.

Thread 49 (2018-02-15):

Make LED display more informative for WiFi config

george08, 2018-02-15:
We're thinking it would be good to introduce:
 [ ] Bi-directional Larson scanner action when we're broadcasting 'museuminabox' network, and someone's trying to join it
 [ ] Left-to-right Larson scanner action when they're setting up their own network
 [ ] Ideally, some kind of error state (random?) if there's a problem
 [ ] Flashing happy big green LED for a bit when they're all done and online

george08, 2018-11-15:
See #89

amcewen, 2018-11-15:
ISTR there was a bit of a problem with trying to change the LEDs from inside NodeRED (apart from the big green one that NodeRED turns on itself).  I assume it's because they get accessed by the progress script outside the NodeRED instance, but didn't spend lots of time getting to the bottom of it.

As I mentioned when closing #89, I think it makes more sense to work out what we might want to use the LEDs to display.  Seems there are three general scenarios this would be useful:
 * During WiFi config, as listed above
 * When downloading new audio files in the background
 * During software updates (when you put the "check for updates" card onto the box) (see #55 for more background)

george08, 2020-02-03:
When the box says "I'll just restart" after using the Update card, the lights should all go off except the left-most orange one, and the normal progress startup lighting should happen, with a "Ready" at the end.

Related: https://github.com/museuminabox/brain-dei-mille/issues/23

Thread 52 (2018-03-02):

Move to new "create a box" workflow

amcewen, 2018-03-02:
Rather than `/setup` showing a list of possible boxes in a drop-down for you to choose from, it should instead let you click a button which will generate a UUID for this brain and ping the cloud API to create a box for that UUID.

If this brain has already been configured, it should also show the UUID, so you can cross-reference it with the cloud admin.  In that case, clicking the button will discard the current config, create a new UUID and configure the brain for that.

For the cloud API side of this, see https://github.com/museuminabox/museuminabox-v2/issues/17

amcewen, 2018-04-13:
This is now implemented and in use in production.

Closed 2018-04-13.

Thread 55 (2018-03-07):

What remote debugging/updating processes do we want/need?

amcewen, 2018-03-07:
Now that we're moving to having deployed boxes connect to the Internet (#8), that opens up the possibility of us connecting to them out in the wild.

So we could...
 * Update the software OTA (Over The Air)
 * Do remote debugging

amcewen, 2018-03-07:
The remote debugging one would most likely be something like creating an SSH tunnel back to our server (I've [done that in the past](https://github.com/mcqn/handy-ansible-roles/tree/master/roles/ssh-tunnel) with Pis deployed in hard-to-reach places), which effectively lets us `ssh` into the Box and then do any of the things we'd normally do while logged in.  So that could let us do upgrades, set up port forwarding to let us see the `http://box.local:1880` screen from afar...

I don't think it should set up the tunnel by default.  Maybe we should create a "Call back to base" tag, similar to the WiFi config one, which creates the tunnel and then next time the box is powered up it would be back to not having a connection back to base.

amcewen, 2018-03-07:
OTA updates are a bigger can of worms, but one that it would be good to open sometime.  When would the updates be reported?  How do we communicate that (and any success/failure) to the user?

We might be able to do most of it by downloading a script that we can run, which can then do pretty much anything...  We'd have to craft such scripts, but...

A lot of it might be doable by just syncing the latest `/home/pi/miab` folder, and ditto for the `node-red-config` folder (or maybe even just the flow).

Maybe if we work out a method for triggering the update, then we can start to move to it for updating the MiaB London boxes, and that'd let us eat our own dog food...

nibrahim, 2018-11-15:
I can't really offer much since I haven't seen the setup on the brain yet however there's one thing that bit us repeatedly last time we were working on an OTA setup and that's the dependency issue for things like python, node, ruby etc. Making some change that'd require changes to the software as well as the Raspian packages would be kind of hard.

My current thought (althougt I'm not sure how practical it is right now for the brain) is to write the application there with a compiled language like go and then an upgrade would just be dropping a new binary in place and restarting the service. A synlink system to revert would be nice too.

Remote monitoring, yes. An ssh channel somehow would be ideal but yeah, it shouldn't be on all the time.

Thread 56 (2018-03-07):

Start versioning the software

amcewen, 2018-03-07:
Given #55, if we're going to do updates (and even if we don't), we'll need to know which version of the software we're currently on.

We should report that back to base, probably in the call to update the audio files (given that it's already in place)

amcewen, 2018-03-15:
The `/api/boxes/:uuid/list.json` endpoint will change to be a `sync` endpoint, given that there's now information flowing both ways from the box to the heart and back.

It'll also become a POST, and receive a chunk of JSON from the box.  At present this will only be the software version that the box has installed.  We're also changing what gets returned slightly, to push the array of prints into a `prints` variable, again so that we can add things in future (e.g. `latest_software_version`, so that boxes can know if they need to upgrade)

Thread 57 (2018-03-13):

Simplify wiring between Pi and Boot Progress PCB

amcewen, 2018-03-13:
The wiring between the Pi and the progress PCB ends up with a couple of crossed wires, which makes it trickier to build up the wiring loom when assembling boxes.  We should rework it for v1 so that it's simpler.

Closed 2018-03-13.

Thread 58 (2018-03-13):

Consider dropping one of the progress LEDs

amcewen, 2018-03-13:
For the v1 hardware, we end up with a wiring loom that has 9 wires to go to the progress PCB and two wires to go to the power connector on the amp.  If we had one fewer LED then we'd only need 8 wires for the progress board and so only 10 wires would be needed in the loom.

That would result in no wires left over and would mean we'd keep the same colour scheme through all of the boards.

amcewen, 2018-11-15:
It didn't.  Feels like there's likely to be bigger PCB changes for the next big round of building we'd do, so I'm going to close this but tag in #86 so it might get considered then (although a lot of that will be about removing wires completely so would hopefully make this a non-issue...)

Closed 2018-11-15.

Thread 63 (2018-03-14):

Capture "hardware ID" at box setup time

amcewen, 2018-03-14:
Now that we've got an ID etched into the case of the box, we should store that in the Heart.  The best way to do that would be to enter it when you go to `http://box.local:1880/setup`, then it can be submitted to the Heart API along with the UUID.

The corresponding addition to the Heart is being tracked in https://github.com/museuminabox/museuminabox-v2/issues/46

Closed 2018-03-15.

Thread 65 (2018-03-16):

Make yellow LEDs light up faster on startup

george08, 2018-03-16:
Gill is announcing she's ready before the lighting sequence is finished :)

amcewen, 2018-04-14:
I've sped it up by 2.5 seconds, but don't have a progress bar here to test it against.  We can tweak it further if need be.

amcewen, 2018-08-03:
There haven't been any reports of the timings not working well of late, so I think this is done.

Closed 2018-08-03.

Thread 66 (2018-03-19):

Help sync/debug Jewish Museum brain?

george08, 2018-03-19:
Hi Adrian,

We're supposed to be delivering the brain upgrade this week, and on Friday, it seemed like the brain (old Raspberry Pi, new software) was glitching a bit, by not always saying "One moment please, I'm just warming up."

Can you help debug tomorrow (Tuesday), please? (I thought I recalled you saying it's a software issue?)

amcewen, 2018-03-21:
New tweak to the startup ordering in the `img` file I shared earlier.  If that doesn't help then I can see what else we can investigate.

Closed 2018-08-17.

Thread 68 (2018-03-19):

Add Gillian & .wav to every Collection by default?

george08, 2018-03-19:
There might be a more graceful way to do it, but can she also appear on box.local/prints so we can set her up while we're also doing/testing Wifi?

amcewen, 2018-03-21:
I think longer term we should end up with a better way to manage all of the "one of these in every box" RFID tags (something to revisit when I'm reimplementing the `/prints` setup UI in #62), but for now I can add something to `/prints` in the same way as we do with the WiFi config tag.

george08, 2018-03-21:
Sounds good!

(BTW office internet is busted so downloads etc hampered for a bit.)

...
George Oates
Director
gfns.uk

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

george08, 2018-04-09:
This would be helpful in the run-up to Smithsonian config work (prob happening next week).

(Makes me wonder if eventually we'll need a special class of Things/Prints - HQ ones.)

amcewen, 2018-04-14:
Thinking about this more, it seems (now that a box can have multiple collections) that we should just have a "Museum in a Box" collection that contains the Gillian and then whatever other HQ prints we need.  Maybe one for "check for upgrades" to let us trigger #55?

I did create a new collection for that, and added a Gillian `Thing` but haven't added it to any boxes yet or created any `Print`s for it.

george08, 2018-04-14:
Good. Wifi too?

...
George Oates
Director
gfns.uk

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

amcewen, 2018-04-14:
Yes and no :-)  The WiFi object is nominally part of this collection, but actually both that and the "check for upgrades" one I mentioned are implemented slightly differently (they don't have any audio data on them) so are included in the `brain` side of things rather than the `heart` Collection side.

amcewen, 2018-11-15:
Yes.  Only possible downside to that would be if a Gillian from one box was booped on a different box you wouldn't know that it wasn't that box's own Gillian (you'd get a "Gillian was booped on box X" boop, rather than a "Gillian from box Y was booped on box X" boop), but that doesn't seem especially important to track

amcewen, 2018-12-18:
They'll all show up as print 650, which is the Gillian welcome object from the [Museum in a Box collection](https://heart.museuminabox.org/heart/collections/104/)

amcewen, 2019-01-15:
Sadly 650 is the *Thing* ID, not the *Print* ID.  We should use the  *Print* ID of 1839 for the Gillian prints, as that will correctly map to the Gillian *Thing*

See https://github.com/museuminabox/museuminabox-v2/issues/139 for the initial bug report.

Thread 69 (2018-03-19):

Load existing prints on to upgraded Jewish Box

george08, 2018-03-19:
Here's the new box:
https://heart.museuminabox.org/heart/boxes/68/

And we need our _existing_ set of prints to play on it:
https://heart.museuminabox.org/backstage/boxes/imprint/243/change/
https://heart.museuminabox.org/backstage/boxes/imprint/231/change/
https://heart.museuminabox.org/backstage/boxes/imprint/229/change/
https://heart.museuminabox.org/backstage/boxes/imprint/227/change/
https://heart.museuminabox.org/backstage/boxes/imprint/225/change/
https://heart.museuminabox.org/backstage/boxes/imprint/223/change/
https://heart.museuminabox.org/backstage/boxes/imprint/221/change/
https://heart.museuminabox.org/backstage/boxes/imprint/220/change/
https://heart.museuminabox.org/backstage/boxes/imprint/226/change/
https://heart.museuminabox.org/backstage/boxes/imprint/230/change/
https://heart.museuminabox.org/backstage/boxes/imprint/228/change/
https://heart.museuminabox.org/backstage/boxes/imprint/222/change/
https://heart.museuminabox.org/backstage/boxes/imprint/224/change/
https://heart.museuminabox.org/backstage/boxes/imprint/232/change/

amcewen, 2018-03-21:
I've given the original box a UUID which means we can (assuming the stuff I've built works, which it seems to) upgrade it rather than replace the box details (also means new boops will be associated with the same box as the old ones).

Needs testing, with the `img` file I shared in Slack.  @CharlieMiab, if you can burn that image to a spare older 8GB SD card (the latest ones are too small :-() and let me know how you get on, that'd be good.

george08, 2018-03-21:
Ok, cool.

Can you please note down the procedure we have to follow in this case?

...
George Oates
Director
gfns.uk

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

CharlieMiab, 2018-06-06:
The prints are now on the upgraded box and the audio has been updated on-site via the Jewish Museum's WiFi. The JM box now has the same script as the Smithsonian boxes and not the custom JM img that Adrian initially custom wrote for it.

Closed 2018-06-06.

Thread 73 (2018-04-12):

Upgrade for /prints page on box.local

george08, 2018-04-12:
pics don't show if titles are in Arabic :)

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

Note: in Chrome it shows a broken image icon, in Safari, shows nothing.

amcewen, 2018-04-12:
Hmm, it should do if there are some in `heart`.  Maybe that doesn't come through properly any more.  Will have a look later

george08, 2018-04-13:
Here's a list of things that would make writing loads of tags quicker/easier:

- show items in a grid (not a long list)
- make the WRITE buttons big
- show an image for each thing (maybe `title={title]`
- if it fails, make it red
- if it works, make it green
- _maybe_ print the console there too (but I can have that in another window)
- display all collections on the box (in a dropdown or tabs or something, but only show the images/WRITE for one collection at a time (and allow switching between them)

Here's a comp:

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

amcewen, 2018-04-13:
Any preference for easy CSS to do the grid-ness?  It's a plain HTML file at the minute, so we don't have any frameworks, etc. hooked in (can do so, especially if they're hosted somewhere else on the Internet and we can just refer to them).

We don't have any images on the Prints in `heart` (at least, not for the Iraq box), which is why you don't already see images...

Not sure if the box knows anything about collections - I don't think it does - so that would require changes in what gets sent from `heart` to implement.

amcewen, 2018-04-13:
They do in `heart`, but not in the stuff that gets exposed via the API to the `brain` side of things.  We can change it longer term, but it'd need changes on both `heart` and `brain` to work.

amcewen, 2018-04-14:
I've got the images working as well now.

george08, 2018-04-15:
(We may want a UTF declaration at some point.)
I'll test it all tomorrow and close if it all seems to work.

george08, 2018-11-15:
See #93

amcewen, 2019-12-03:
A list of hyperlinks to jump to each collection would be nice too.

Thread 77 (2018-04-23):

Add threadlock to the nuts holding on the speaker

amcewen, 2018-04-23:
The nuts and bolts holding the speaker on can vibrate loose.  We should start using nyloc nuts or threadlock on the bolts.

CharlieMiab, 2018-06-05:
BOM has been updated to use Nyloc locking nuts.

Closed 2018-06-05.

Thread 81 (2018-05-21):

Allow prints configured at HQ to be sent to a remote Box

george08, 2018-05-21:
Lots of emerging use cases for this... e.g. can we send a new sticker for the objects that are breaking in Sparklab in DC? Can we send new Collections to a remote box?

Would be good to discuss this, perhaps.

amcewen, 2018-05-30:
It's not perfect, but we can do this at present by using the `/upgrade` feature to set a box in HQ to be the same as a remote box.  Then `/prints` would let you write tags that would be the correct ones for the remote box.  You'd just need to remember to set the HQ box back to its correct version with `/upgrade` again at the end (so we didn't get false entries in the boop log)

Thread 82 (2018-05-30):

Report MAC address back to heart

amcewen, 2018-05-30:
Given some of the in-the-field debugging we're doing, it would be handy to know the MAC address for each box.  Generally to make life easier for sysadmins trying to get the box onto trickier wifi networks.

The easiest way (I think) would be to include it in the info sent when checking for content updates.

amcewen, 2018-12-19:
The brain side of this is done, although the info isn't currently stored anywhere on `heart`.

amcewen, 2019-10-28:
Bug in `heart` has been fixed, and MAC addresses are showing up okay.

Closed 2019-10-28.

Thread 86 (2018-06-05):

Integrated PCB design

amcewen, 2018-06-05:
An issue to collect thoughts/ideas/wishlist items for the next revision of the custom PCB.

Combining the amp and possibly an i2s DAC with the progress PCB could reduce the amount of wiring we have to do in assembling the box, and would improve the availability (and maybe the lead time) for sourcing amp circuits.

Input options would be basically the same as we have now: a bunch of IO pins to toggle LEDs, and either stereo analogue audio or i2s audio.

Output would also be the same - 3.5mm stereo audio jack and a single speaker (I imagine we could cope with two speakers if the design required it)

I think the analogue volume control is also important.

amcewen, 2018-06-05:
Some amp options (as the YDA138 chip our current design uses seems to be hard to source):
 * TPA3136 - no volume option, would need to add that separately; easy-to-solder package; good documentation for mono speaker operation
 * TDA7491 - volume control; stereo amp with no indication of mono circuit; reasonably easy-to-solder package
 * MAX9768 - volume control; mono amp; hard (it's 4mm x 4mm in size) to solder package

All of these options are surface mount.  If we move to that for the amp, is it worth doing the same for the LEDs?  That might make sense anyway (with a suitable right-angle light pipe) if we need to line up the LEDs with the centre-line of the potentiometer.  It would mean the LEDs didn't protrude like they do now, and the green ready LED wouldn't be larger, but that has caused confusion in deployment, so that might not be a bad thing...

amcewen, 2018-07-23:
Having sourced another YDA138 amp, and checked the [datasheet for it](https://pdf1.alldatasheet.com/datasheet-pdf/view/205149/YAMAHA/YDA138.html) it looks like our existing supply was lying about the chip it uses.  According to datasheet, the YDA138 operates from 9-12V (and the one I bought bears that out - if I drop is supply below 9V it stops outputting any sound), and is also a bigger chip (it's possible that it's available in different packages, although the correct chip has more pins too...).  Annoyingly the chip on the existing amps we were using has been scraped off by the supplier, so i can't easily work out what it is.

The TPA3116 chip looks like it could be another candidate.  There are some boards available which use this:
 * [Mono, barrel-jack for power supply, claims it needs 8-25V so not clear it'll run off 5V](https://www.ebay.co.uk/itm/TPA3116-100W-Subwoofer-Digital-Power-Amplifier-Board-TPA3116D2-Amplifiers-ZY/123060744101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)
 * [Stereo, screw terminals for power, claims to run from 12V-24V so not clear it'll run off 5V](https://www.ebay.co.uk/itm/TPA3116-2x100W-Dual-Channel-Audio-Speaker-Digital-Amplifier-Board-12V-24V-AT7/253511403604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)
 * [Stereo, headers for all connections, claims to be 12-24V supply, but tiny board](https://www.ebay.co.uk/itm/TPA3116D2-50W-2-DC-12-24V-Digital-Amplifier-Board-Class-Dual-Channel-Stereo-AMP/183302562860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)
 * [Stereo, screw terminals for power, 5-24V supply](https://www.ebay.co.uk/itm/TPA3116D2-Dual-50W-Channel-Stereo-Digital-Amplifier-Board-Power-Amp-5-24V-TE743/163043551899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)
 * [Mono, screw terminals, would need the volume potentiometer adding - but that would allow us to choose a squarer one - also claims only 12/24V supply](https://www.ebay.co.uk/itm/TPA3116-D2-DA-DC-12V-24V-100W-Mono-Channel-Digital-Power-Audio-Amplifier-Board/152990339062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)

Annoyingly they all seem to be sourced from China, despite a few claiming to be supplying from the UK (unless they've got UK warehousing, but that seems unlikely), so it'll take a while for us to get hold of any to test with.

amcewen, 2018-07-26:
I've built up a circuit with the MAX9768, which works, but is disappointingly quiet.

infovore, 2018-07-26:
@amcewen I think the MAX9768 has the same issues I had with the PAM8320: both chips have a supply range is listed as 4.5V->14V. The PAM8320 just about works at 5V but clips really easily and isn't very loud: it has no volume and _no headroom_. For an experiment, I ran a PAM8320 at 9V and it sounded brilliant, and loud. But you definitely don't get full performance at that very very low end of the voltage range.

infovore, 2018-07-26:
Next up: I'm going to investigate a TI [LM4860](http://www.ti.com/lit/ds/symlink/lm4860.pdf) "Boomer" - another chip designed for 5V supply, 1-and-a-bit-W output into 8ohm loads. Unlike the Diodes chips, it looks like I can increase the gain on the TI if I want to up to 10x, which is useful from a volume perspective - we still attenuate on input, but have the possibility to set the maximum output gain higher.

It's a class-AB amp. One thing that is useful about it is as well as a 'shutdown' pin (for massive shutdown when running on battery) it also has a 'headphone disconnect' pin, meaning that if you have a stereo headphone jack with normalising pins, you can easily disable the amp when headphones are plugged in - I forget if the Brain has a headphone jack, and if it's just wired to the Pi in parallel. Anyhow, this way around, you could potentially have a volume knob for both amp/headphones, and just swap ins/outs on connection.

I should know more about this chip by Friday 27th.

infovore, 2018-07-26:
And finally - regarding the amp chip, at the moment, I'm exploring basically building a replacement stand-alone board - keeping the amplifier/volume component a separate unit, with screwterms for all key connections. We've still got the capacity to make something that will fit precisely, but means we can move to a single "monolithic" brain PCB in a second step.

amcewen, 2018-07-26:
@infovore I'm not sure that's the case with the MAX9768 - I didn't do lots of testing with it at higher voltages, but did try it ~12-14V range and didn't get much more from it.

There is a headphone jack on the box, which is wired in between the Pi and the amp and breaks the connection to the amp if you plug something into it.  The volume control only affects the amp (at present).

And stand-alone board is fine.  This issue was raised as a longer-term idea to explore, when we thought we had the amp situation resolved for the short term...
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
amcewen, 2018-08-01:
Actually, two more questions:
  1. Are you assuming a panel mounted pot for that PCB, and if so does it mount directly to the PCB?  That'd be preferable for us, but I can't tell from the picture if the mounting holes for it are near enough to the edge of the PCB for that
 1. Is that from Euro Circuits?  (Curious, rather than concerned/opinionated)

infovore, 2018-08-01:
@amcewen -

> Are you assuming a panel mounted pot for that PCB, and if so does it mount directly to the PCB? That'd be preferable for us, but I can't tell from the picture if the mounting holes for it are near enough to the edge of the PCB for that

Yes: on the 'right' of the above image, the two large holes and the three in a row beneath it are a panel-mounted pot on the _other side of the board. So: screwterms and components on the back side, pot coming out the other side, with a screw mount to the front of the brain. Does that make sense? I took measurements and think this will fit in place with no bending/bodging around the Pi.

> Is that from Euro Circuits?

the screengrab is just from EAGLE's "manufacturing" tab; if I got some fabbed, I'd do it at AllPCB who are doing five-day turnarounds, and five-six of these boards would be $10. (They are clearly doing this as a loss-leader for custom).

amcewen, 2018-08-01:
Ah, so the shaft of the pot is perpendicular to the PCB rather than parallel to it?  I'm happy to trust that you've got it in hand if it's something you've thought of, was mostly checking it had been a consideration.

That does seem a good price for that turnaround!  All sounds good, get them ordered :ok_hand:

infovore, 2018-08-02:
@amcewen yep, looks like this:

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

infovore, 2018-08-02:
OK - having demoed this to George, I'm going to order a prototype run of 5 boards, and parts for them.

I've also got a [BOM at Octopart](https://octopart.com/bom-tool/EVtU92Xq) which includes absolutely everything except the pot. At volume of 100, with a ~£1 pot and a board that AllPCB quote at 43 cents for 100, BOM comes in at £4-£5.

(As for renders - well, that's really just CAD software that happens to integrate with PCB software, but it sure does help visualise stuff spatially!)

amcewen, 2018-09-17:
The new amp is nice!  Have you got details of the volume pot?  That's not listed on the BOM at present.

And can I get the source files for the PCB - both for future reference, and also to tweak it to use 5.08mm pitch screw terminals (a 6-way rather than 3 2-way to reduce the number of components to put on the board, but mostly a slight size increase because of the pre-crimped dupont connector wires we'll be inserting into them)

george08, 2018-09-18:
@infovore can we please have a file for the PCB? it's time to place an order for 80 of 'em. Also curious about your Knob Man...

infovore, 2018-09-19:
Hello! I'm on vacation in a farmhouse in Italy with poor connectivity at the minute, hence quiet. Back on Monday - can I get you some files then? I also have to patch up the logo. If you absolutely need it before Monday, I can see what I can do, but internet here is a bit crap.

Pots: the pot is a [9mm Alpha pot](https://www.thonk.co.uk/shop/alpha-9mm-pots/). That link is where I get them from - Thonk, in Brighton. £1.02 ex vat for quantities of 50+. Really high quality, metal shaft.

george08, 2018-10-08:
@infovore can you please specify exactly which potentiometer I'm buying? (there are about 20 listed on the page)...?

infovore, 2018-10-08:
@george08 of course, sorry I didn't clarify above:

On [this page](https://www.thonk.co.uk/shop/alpha-9mm-pots/), `VERTICAL: A10K AUDIO` is what you want to purchase. The bulk discount kicks in automatically when you order a quantity.

george08, 2018-10-17:
Also, @infovore - who's the volume knob dude you like, please?

amcewen, 2018-10-17:
And while you're here @infovore, we're getting to the ordering PCB stage, so if you can share the Eagle files (either for your original, or the 0.2"-spacing revision if that's in a reasonable state) that would be ace.  (either email them over, or stick them in this repo in [Physical](https://github.com/museuminabox/brain/tree/master/Physical)/amp (or similar), if you've got access.  Whichever's easiest.

amcewen, 2019-03-05:
Doing some digging into possible I2S DACs to use so we can eliminate the wiring between the Pi and amp, the PCM5102 and PCM5122 both look like good candidates (not many components needed, evidence of it already working on a Pi, ~£2/chip).  I've ordered a couple of PCM5102 breakout boards to try, and there's a [PCM5122 breakout board](https://oshpark.com/shared_projects/MmVdE7fl) available too, but we'd have to solder the parts on ourselves.

amcewen, 2019-06-19:
All the work is done for this on the v1 box design.

Closed 2019-06-19.

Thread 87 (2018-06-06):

Start-up audio is temperamental/inconsistent

CharlieMiab, 2018-06-06:
Boxes don't always play both 'one moment please I'm just warming up' and 'ok, ready to go' notifications on start-up. Sometimes only the first notification plays, sometimes only the second and sometimes both with no obvious reasoning for why.

george08, 2018-11-15:
Need to be able to replicate this.

amcewen, 2019-01-16:
Haven't seen it miss the "ok, ready to go" audio, but the "one moment please" being missed happens fairly often

CharlieMiab, 2019-01-16:
Yes we're still experiencing it with the 80 boxes in HQ and it's the "one moment please" audio that is missed not the "Ok, ready to go".

amcewen, 2019-01-16:
Have had 20 boots (a combination of warm [restarting in software] and cold [pulling power and starting from scratch]) without any problems in it, so fingers crossed the timing is now sorted for the soundcard to always be ready when we play the "one moment please" audio.

Closed 2019-01-16.

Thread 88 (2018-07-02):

Stubborn writing tag 'Try again' notification requires box restart

CharlieMiab, 2018-07-02:
When writing tags often a tag won't work when clicking 'write' and the 'Try again' notification will come up immediately. Multiple clicks don't solve it and neither does removing and replacing the object on the box. The only way around this is to restart the box and refresh box.local:1880/prints. Normally fixes the problem but of course slows down the process of writing a new collection.

george08, 2018-11-15:
See #93

Closed 2018-11-15.

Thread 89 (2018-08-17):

Make progress LEDs twinkle if there's an update happening

george08, 2018-08-17:
I'm working on the Swedish National Heritage Board's box for delivery. The collection they made had five things in it, and then they added another four. I've added the four new things using the admin UI, and checked it on Heart, and all seems well.

https://heart.museuminabox.org/heart/collections/105/

But, when I go to configure the stickers on the box a) I can't see the new things in the list on /prints, and b) I don't know if the box is trying to update itself. (I've restarted the box three times now, and the new things aren't showing up on /prints, still.)

george08, 2018-08-17:
Maybe we could even have the box speak, and say "Checking for updates. One moment, please."

amcewen, 2018-11-15:
The things-not-showing-up-in-`/prints` is covered in #90.

By "update", I'm assuming you mean downloading-new-audio-files (as that's all that updating the set of prints means to the `brain`), rather than putting-new-software-onto-the-`brain`.

I'm going to make #89 a bit more general, and we can group together all of the "LEDs to indicate things happening" discussion there.

Closed 2018-11-15.

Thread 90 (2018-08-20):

Confirm that removing a collection from Box page on Heart does remove it from a Box

george08, 2018-08-20:
(Otherwise, George will go insane.)

I'm trying to fix separate issue on https://heart.museuminabox.org/heart/boxes/86/ by removing collections and re-adding them to rewrite chips. (None of the objects played the full track.

I've rejigged the Collections list on Heart, but box.local:1880/prints is still showing the old set...

amcewen, 2018-11-15:
Hmm, `/prints` downloads the list of prints from `heart` whenever it runs, so showing an old set would either mean that `heart` was providing the wrong set, or your browser was caching it locally.

I'll get the `brain` to set its headers so that the browser shouldn't cache things (it'll be whatever the default is at present), but outside of that it'd be a bug in `heart` rather than `brain`.

The objects not playing the full track will be a duplicate of #76, which we need to fix.

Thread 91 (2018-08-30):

Allow one set of objects/stickers to trigger 2+ sets of audio

george08, 2018-08-30:
Had a good chat with Sharyn from Tomb in a Box this morning... she has just taken Tomb in a Box to Year 7/8/9 kids in rural Victoria. Her contention is that teachers/schools would be OK paying for a single Collection and a single Box if the Box could play more than one set of audio.

So, one set of objects could trigger more than one set of audio. Imagine there's some switch on box.local somewhere that says "use this set of audio until otherwise instructed"... you take the Box/Objects into your Year 7 class, and use that. Once that's finished, you head back to box.local and switch the audio set to Year 8s, then go to that class.

Interesting idea, and could prove efficient!

Let me know your thoughts...

(She and I are in v early stages of thinking through our first commercial partnership, and she sees this as the minimum product development for her to engage.)

amcewen, 2018-11-15:
Feels like you'd have a "default" audio that it could fall back to if you hadn't switched to a specific subset (so you can override just a subset of the objects).  The switch could be a special class of tag, if that's an easier interaction model than connecting to `box.local` - put that object on first, then until it's powered off or your put another object on to switch to a different set, it'll run with that one.

I'm not 100% sold on making the objects/box have a modal interface, but I can see how it would work in that scenario.  Are there any other similar cases - making your own recordings to replace the "official" ones feels like an obvious one.

Technically, creating sub-folders with the same content names in them seems the obvious way to implement it on the `brain`, but it would need `heart` to keep the same filenames across sets so the tags didn't need to change.  And we'd need to work out what the UX would look like for setting it all up on `heart`

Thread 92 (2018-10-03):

Switch to the RC522 RFID reader

amcewen, 2018-10-03:
Are any of the other RFID/NFC readers better/cheaper?

amcewen, 2018-10-05:
The RC522 seems to work okay - it seems to read all the tags okay (all the ones I've got knocking around anyway).

Looking on Aliexpress, they're available for ~$1.50 each ([for example](https://www.aliexpress.com/item/Free-Shipping-13-56MHz-I2C-SPI-RFID-Module-For-Arduino-MF-RC522-RC-522-Reader-Writer/32803648297.html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,searchweb201602_1_10065_10130_10068_318_10547_10548_10696_10192_10190_10084_10083_10618_452_10307_10820_532_10821_10301_10303_204_10059_10884_10887_100031_10103,searchweb201603_2,ppcSwitch_0&algo_expid=dbdcf74b-3c9b-4488-9a67-ec0b12cd6da8-4&algo_pvid=dbdcf74b-3c9b-4488-9a67-ec0b12cd6da8&transAbTest=ae803_4&priceBeautifyAB=0)).

The only downside to them seems to be that they don't have an LED to indicate when they've detected a card, so there's not that additional bit of feedback to let you know you've got the tag in the right place.

george08, 2018-11-15:
Should we close this and make a new Issue about any code rewriting that's required @amcewen?

amcewen, 2018-11-15:
Don't think it makes a lot of difference.  The rename makes it more obvious that it could also collect the code changes here too - and that's the remaining bit of work required now.

amcewen, 2018-12-19:
Code is done for this, and integrated into the rest of the brain.  Needs plenty more testing but we can open new bugs (or reopen this) if we find any problems.

Closed 2018-12-19.

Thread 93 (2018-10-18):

Need clearer/designed debug output for pilots

george08, 2018-10-18:
The stuff that splats out of box.local:1880 debug tab is a little weird. Can we design that and put it in an iframe, with English/written responses that make a bit more sense to mere mortals?

E.g.
- OK! That sticker is written.
- Can't find the RFID tag. Please try again?
etc

george08, 2018-11-15:
@thibaut-evrard is thinking about this too... wondering if we should pop box.local UI in an iframe in the heart system, too.

amcewen, 2018-11-15:
Arguably we shouldn't be using the NodeRED debug output as a UI :-D

There'll be a load of it that we don't have any control over.  It feels like this is mostly a "we don't trust the output on `/prints`" rather than "we should expose the internal debug output to the end user", is that right?

The output on `/prints` when writing tags should be lots better since the redesign work in the run up to the big commission, but there might still be glitches/bugs in it.  Plus we could look at designing that better too, as is already mentioned in #73?

george08, 2018-11-15:
Yep - agreed that the raw NodeRED is a little hard to swallow :)

I'm gathering bits I think we should design properly with a human in mind under this label: https://github.com/museuminabox/brain/labels/user%20interface

amcewen, 2018-12-05:
it would be good to add audio versions of the success/error messages too.

george08, 2018-12-13:
@amcewen what do you reckon is the right approach here, for the pilot?

it is a little bit that "we don't trust the output on /prints", since the test of booping the newly minted object's sticker and expecting audio doesn't always work, and it isn't clear why.

Is there a list of the debug messages anywhere? Is it the case that there is only one true "Success!" state of the process? If so, can /prints just wait for that one?

I guess this will be helped a bit by the "download all the audio you need" button on the /prints page, too, if some of the inconsistency is caused by a lack of audio.

amcewen, 2018-12-19:
With the better audio download stuff from #100 and #76 I think this will work better.  Not going to do any more on it for the pilot, but will leave it open so next time we're triaging we can confirm that we aren't still seeing problems with the tag writing flow.

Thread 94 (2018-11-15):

If you put an object back on the Box within (2 seconds?), keep playing the track where it left off

george08, 2018-11-15:
This is a nice to have - was a suggestion that came up testing with someone for the first time... It doesn't take too long to learn that the track starts from the beginning, but perhaps, if you put the object back on quickly, maybe it could keep playing.

george08, 2019-12-03:
I don't think we need this. If it comes up again, we can reassess.

Closed 2019-12-03.

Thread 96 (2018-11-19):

Switch to using version numbers for skull design

CharlieMiab, 2018-11-19:
We've uploaded the latest skull design, MIAB-skull-v1.2, to the brain/physical directory. From now on we will use this as the main location for the current skull file in order to keep track of version numbers. A copy should also be uploaded to the drive. This should please Adrian!

Closed 2020-01-27.

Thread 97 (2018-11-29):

Which wires to we attach to the Aux Out?

george08, 2018-11-29:
Hi @amcewen - we've started the prep for box making, and have a question about Step 4 on this plan:

https://github.com/museuminabox/brain/wiki/Getting-components-prepared

We've trimmed and are stripping the double-ended Aux jacks, but there are four wires inside, not three like last time: white, red, green and black.

In the previous box, the Aux Out has green, white, and red soldered to it, but we weren't sure if that's transferable, since we now have an extra black wire...

amcewen, 2018-11-29:
RTFM ;-)  https://github.com/museuminabox/brain/blob/master/Physical/README.md#wiring-the-audio-circuit has more detailed instructions about the wiring (and the previous box will have a blue or black wire that's not connected, but it'll have been snipped off near the insulation as it's not needed).

However, you're right that the old colour-coding won't necessarily match the new colour-coding.  The best way to check would be with a multimeter, but I don't think you've got one?  As a fall-back you could create a circuit through the wire to check that the right bit is connected, using a Pi, a few jumper wires, and an assembled Boot Progress board:
  1. Connect a wire to one of the +3V3 pins on a Pi (see [this wiring diagram](http://elinux.org/RPi_Low-level_peripherals#Model_A.2B.2C_B.2B_and_B2))
  1. Connect another wire from one of the GND pins on the Pi to pin 9 on the Boot Progress PCB (see [the pin-out for that here](https://github.com/museuminabox/brain/blob/master/Physical/README.md#bootprogressboard))
  1. Connect a wire to pin 8 on the Boot Progress PCB
  1. You'll have two not-connected wire ends from the other ends of the wires in step 1 and 3.  Hold one of the wires against one of the bits of the 3.5mm jack plug that you want to test, and then hold the other wire against one of the coloured wires of the aux cable.  If the LED on the Boot Progress PCB lights up then that bit of the 3.5mm jack is connected to the coloured wire you chose.  If it doesn't work through the rest of the coloured wires until you find the one that's connected.
  1. Note down the connection you've just found
  1. Repeat from step 4 for the next bit of the 3.5mm jack plug, until you've worked out which is which for all of them.
  1. You'll now know which colour is which for the tip, ring 1 and ring 2 connections listed in https://github.com/museuminabox/brain/blob/master/Physical/README.md#wiring-the-audio-circuit

amcewen, 2018-11-29:
For bonus points, update https://github.com/museuminabox/brain/blob/master/Physical/README.md#wiring-the-audio-circuit to document the latest wiring colour-coding so we don't have to run through the process again next time we're building boxes :-D

george08, 2018-11-29:
@CharlieMiab want to take a crack at this?

george08, 2018-12-13:
Cables are all connected now.

Closed 2018-12-13.

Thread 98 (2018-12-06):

Do a design rev on the Progress Bar PCB to include human-readable labels for the various sections

george08, 2018-12-06:
I like the way Tom added labels (and version number etc) to the amp board. Hoping for similar on Progress Bar!

george08, 2018-12-06:
- 1x orange dot
- 6x yellow dots
- 1 big mama LED

- single resistor
- resistor array
- 9x right angle header

amcewen, 2019-06-19:
We're not planning another rev of this progress board now.

Closed 2019-06-19.

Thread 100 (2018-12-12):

Update audio more frequently

amcewen, 2018-12-12:
We should sync our audio content more often - when `/prints` is loaded, and also on a regular interval in the background.

Also have a "Update audio" button on `/prints` to manually kick off a sync

amcewen, 2018-12-17:
Loading `/prints` kicks off a download in the background; there's still one kicked off when we first boot; and then it syncs every 23 minutes.

And there's a manual "download now" button on `/prints`.  I'm sure it could be styled/laid out better, but we can do that as part of a "how does this look" pass when #101 is done.

Closed 2018-12-17.

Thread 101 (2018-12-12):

Group prints by collection

amcewen, 2018-12-12:
The `/prints` page should group the prints by collection, and have an anchor for the collection ID so we can jump to it with `/prints#collection-something-or-other`

amcewen, 2018-12-12:
The `heart` changes are being tracked in https://github.com/museuminabox/museuminabox-v2/issues/97

amcewen, 2018-12-19:
This is all implemented now, including the latest styling/layout/wording changes from @george08.

Closed 2018-12-19.

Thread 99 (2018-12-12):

Add links/nav to /setup

george08, 2018-12-12:
Can we please add the nav bar from the /prints page to other pages on box.local (especially if we're going to be showing this to MYOMB pilots).

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

http://box.local:1880/upgrade
http://box.local:1880/setup

george08, 2018-12-13:
@amcewen I'm happy to do this, if you can please point me at wherever the html/markup is for those pages... had a hunt in the repo, but couldn't track 'em down!

amcewen, 2019-12-03:
This was done, and we no longer have `/setup` or `/upgrade`, so we can close it.

Closed 2019-12-03.

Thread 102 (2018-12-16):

Remove soft-volume script

amcewen, 2018-12-16:
Since the experiments with the square box and the Pi Zero we've had a script on the system to allow two buttons to change the volume.

That's no longer needed, as even if we switch to the Pi Zero we'll keep the new amp board with a physical pot.  The script soaks up lots of CPU time, so getting rid of it will perk things up a tiny bit too.

Closed 2018-12-17.

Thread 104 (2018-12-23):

Third yellow LED from the green one sometimes flickers at startup

amcewen, 2018-12-23:
Quite often when booting up (but not always), the third yellow LED will come on half-brightness and then full brightness *before* it's reached in the proper sequence

amcewen, 2018-12-23:
Pin 18 is also the PWM pin, and it seems that sometimes that has an indeterminate state while it's booting up.  So we need to move that LED to use a different pin - pin 4 is nearby and has been fine with all the testing I've done with it.

The old wiring looks like this...
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

And the new wiring is like this...
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

So we'll need to move the purple wire sixth pin from the left on the top row and move it to the fourth pin from the left on the bottom row.

Closed 2018-12-23.

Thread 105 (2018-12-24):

Optimise initial config of new Box

george08, 2018-12-24:
What can we do with a "bare metal" Pi and a Wifi network in terms of getting our software on to the SD cards... Is there any better alternative than manual writing of SF cards?

amcewen, 2019-10-30:
There are services which will do it - like https://www.easyreplication.co.uk/flash-cards/ (dunno if they're any good, just one I found)

It might also be possible to get some USB micro-SD card readers and write more than one at a time from each computer?

amcewen, 2019-10-30:
There's also [this project to build an SD duplicator with a Raspberry Pi](https://github.com/aaronnguyen/osid-python3).  Maybe we should buy a couple of the USB micro-SD card readers that uses and I can try building one (and if it works with a couple, then we can buy some powered USB hubs and more USB micro-SD card readers and expand it to write up to 26 SD cards at once)

george08, 2019-11-05:
Related: #122

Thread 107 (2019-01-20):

Add images to the WiFi and Update cards in `/prints`

amcewen, 2019-01-20:
Proper home for https://github.com/museuminabox/museuminabox-v2/issues/147 :-)

Closed 2019-01-20.

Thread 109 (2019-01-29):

List Admin collection at the bottom of /prints

george08, 2019-01-29:
People will be looking for their stuff first.

Also, might be nice to hide our new "OK! Here's what to do:" section under a tab or a hidden div or something, labelled "Instructions" or similar.

amcewen, 2019-12-09:
As part of the fix for #121, I moved the admin objects set to last on the page, and the "Try Me" collection to the penultimate collection in the list.

Closed 2019-12-09.

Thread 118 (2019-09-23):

Update old SL030 boxes for latest software

amcewen, 2019-09-23:
The current upgrade path for any boxes with the SL030 RFID reader stops at version 0.9.2.

We should work out the upgrade options to allow the newer software improvements to be back-ported to the older hardware.

amcewen, 2019-10-07:
Done and tested on both the super-old holey box, and HQ3 down at HQ.  Now awaiting any reports of success/failure from the customer.

Closed 2019-10-07.

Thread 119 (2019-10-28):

WiFi setup script should report captive portals

amcewen, 2019-10-28:
When the configure-wifi script finishes and tests whether it can connect to the Internet, it should be able to spot the difference between couldn't connect at all and got a response but not the page we expected, and work out if that's likely to be a captive portal.

We should report the difference to the user.

george08, 2020-01-20:
"Hmm. I'm trying to connect to that network, but it's asking me for more details, like an extra setting, but we can't provide that."

(or something)

amcewen, 2020-01-20:
Got the test page online, and the code written to fetch it and check its contents.  Currently it's only wired into the "check for updates" flow (that's easier to test the different scenarios first as it doesn't involve dropping off the WiFi).

At the moment it reports errors just as a string - next step is to implement custom error classes (e.g. in https://medium.com/@xjamundx/custom-javascript-errors-in-es6-aa891b173f87) so I can then handle them correctly.  Then add it to the WiFi config flow too.

george08, 2020-01-21:
Cool!

amcewen, 2020-03-02:
I've extended the check-for-upgrades and the configure-wifi flows so they (try to) detect any captive portals, and also provide better feedback for WiFi problems.

We'll need three new audio clips please @CharlieMiab, and maybe updates for some of the existing ones.  At present the same error clips get used for both the update and the configure-wifi flows, but they can be different if need be.

The flows now are as follows:

### Configure WiFi
 * Plays `configure-wifi.wav`
 * Runs the WiFi config script, which creates the MuseumInABox WiFi hotspot and provides the web GUI to configure your WiFi network
 * When the user has entered their WiFi details, or if they leave it 2 minutes without doing anything...
 * Play the **new** `check-the-wifi.wav` which let's the user know it's checking to see if things worked
 * There'll be a ~10 second pause while it waits for the WiFi to connect and then checks to see if we're online
 * if...
   * ...it worked, it'll play `wifi-works.wav`
   * ...it failed and it looks like we're behind a captive portal, it'll play the **new** `captive-portal.wav`.  We won't be able to work round that, so try a different WiFi network.
   * ...it failed and we've got an IP address but didn't get a web page, it'll play the **new** `wifi-but-no-internet.wav`  So connecting to the WiFi worked, but we can't get from that WiFi network out to the Internet for some reason.  Check if there's a problem with that network's connection to the Internet, or try a different WiFi network.
   * ...it failed and we don't seem to be connected to WiFi, it'll play `wifi-failed.wav`.  Either try again or try a different WiFi network.

### Check for upgrades
 * Plays `checking-for-content.wav`
 * Checks to see if we're online. If...
   * ...it worked, it then syncs any content, then plays `collections-updated.wav` and the rest as usual
   * ...it failed and it looks like we're behind a captive portal, it'll play the **new** `captive-portal.wav`.  We won't be able to work round that, so try a different WiFi network.
   * ...it failed and we've got an IP address but didn't get a web page, it'll play the **new** `wifi-but-no-internet.wav`  So connecting to the WiFi worked, but we can't get from that WiFi network out to the Internet for some reason.  Check if there's a problem with that network's connection to the Internet, or try a different WiFi network.
   * ...it failed and we don't seem to be connected to WiFi, it'll play `wifi-failed.wav`.  Either try again or try a different WiFi network.

george08, 2020-03-02:
Related (usability issue): https://github.com/museuminabox/brain-dei-mille/issues/25

amcewen, 2020-03-03:
For reference, when an Android phone encounters a captive portal it pops up a notification saying "Sign in to WiFi network required", so maybe we could say something like "this WiFi network needs extra sign in steps that we can't complete"?

amcewen, 2020-03-18:
This is all done now.  If it encounters a captive portal it now forgets that network, so it'll be less likely that someone will accidentally join a captive portal network and then get trapped there.

CharlieMiab, 2020-03-18:
_Adding the testing I did for the captive portal test .img for reference_

In the Royal Armouries Museum:

1. Turned the Box on and Booped the WiFi Card
2. Using my iPhone, selected the MuseuminaBox WiFi network and the pop-up appeared.
3. Chose the 'Royal Armouries Free WiFi' network, left the password field blank and submitted.
4. Heard the robot-brummie saying 'Give me a second to check if that worked', waited a few seconds, then heard 'I may be behind a captive portal'.

Repeated this process three times, turning the Box off after each try and experienced the same flow as listed above.

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

Closed 2020-03-18.

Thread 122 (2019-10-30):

Instantiate Box in the DB when they are built

amcewen, 2019-10-30:
Migrated from https://github.com/museuminabox/brain-dei-mille/issues/17:

@george08:
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

> We've been thinking through production process/timing etc and thinking that configuring boxes is quite time-consuming.

> @Rjevski and I had a quick chat about this at HQ. Lots of options...

amcewen, 2019-10-30:
We'd need a way to cope with "box upgrades" too, so we don't generate unnecessary boxes in the database each time we write an image to replace an SD card in a box (i.e. cases where we'd currently visit `box.local:1880/upgrade`)

Rjevski, 2019-10-30:
For box upgrades it becomes a bit difficult - if the upgrade is online we can have two partitions on the card (one data partition and one system partition, like Android and OpenWrt devices) and the upgrade only overwrites the system one.

If it’s a physical SD card replacement then it becomes more difficult.

Maybe we can just use an existing hardware ID like the MAC address?

Sent from my iPhone

On 30 Oct 2019, at 16:08, Adrian McEwen <notifications@github.com> wrote:

We'd need a way to cope with "box upgrades" too, so we don't generate unnecessary boxes in the database each time we write an image to replace an SD card in a box (i.e. cases where we'd currently visit box.local:1880/upgrade)

—
You are receiving this because you were mentioned.
Reply to this email directly, view it on GitHub<https://github.com/museuminabox/brain/issues/122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>, or unsubscribe<https://github.com/notifications/unsubscribe-auth/AK4C6PXMEZHA5DHXUKFJ5YDQRGIOLANCNFSM4JGZ4FOA>.

Rjevski, 2019-11-05:
I've updated the issue to reflect that we've decided to instantiate boxes manually when we build them (and get the config file on the SD card).

Rjevski, 2019-11-05:
For speaking its hardware ID out loud we could use an online text-to-speech API and generate a file the box can download and play on every boot.

Closed 2019-11-13.

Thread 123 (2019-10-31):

Upload audio in mp3 and other file formats to Heart

CharlieMiab, 2019-10-31:
When creating/editing object audio we can currently only upload in .wav file formats, this is likely to add an additional hurdle for many users.

amcewen, 2019-11-01:
I think this is more a `heart` issue than a `brain` issue - we chose `.wav` files because they start playing a second or two faster (as there's no decoding to do) when you boop an object.

We _could_ do the conversion on `brain`, but it's more sensible to do it when the file is first uploaded, so that'd be on `heart`.

I've moved this over to https://github.com/museuminabox/museuminabox-v2/issues/213

Closed 2019-11-01.

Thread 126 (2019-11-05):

Make boxes fetch their config from the boot partition

Rjevski, 2019-11-05:
We no longer want the boxes to register themselves on first boot like they currently do.

Instead, the boxes should expect a unique configuration file in their boot partition and use that as their identity (UUID, etc). If the file is missing the box should refuse to start and speak out an error message.

amcewen, 2019-11-08:
@Rjevski made a couple of commits towards this:
 * https://github.com/museuminabox/brain/commit/aac3ac145c70c9a69acad2313bf52e898b254d63
 * https://github.com/museuminabox/brain/commit/172a6786cbeff1e642e77aab9dca6f321032cd14

The NodeRED flow needs to load the config from the new location, and needs to not play the "OK, ready to go" audio if the config file isn't there.  I'm thinking it might be better to move the "this box isn't configured" warning audio to that check too, so the check only happens in one place.

We also need to record a final version of the "box not configured" audio - it _shouldn't_ ever happen to a box out in the wild, but we should have user-friendly message just in case.

amcewen, 2019-11-08:
Have made most of those changes - still needs better audio, and will upload a test `img` for you to test the `heart` side of saving the config to SD card

Rjevski, 2019-11-08:
Thanks! Does this prevent the box from starting if the config is missing? Because what I observed previously is that it would still work and read objects even if the config failed to load.

Part of me actually wants the check to be done as a systemd dependency to Node Red so the app doesn't even start if the config is missing.

amcewen, 2019-11-11:
No, it doesn't prevent the box from starting if the config is missing, because the box should gracefully degrade its functionality - if the config file somehow gets corrupted/deleted out in the field the user will get the warning when it first boots up but any content already on the box will still work.

amcewen, 2019-12-09:
New, friendlier audio added.  So this is now all done.

Closed 2019-12-09.

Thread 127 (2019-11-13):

"killall play" is returning an error

Rjevski, 2019-11-13:
In the Node Red flow, `killall play` is sometimes returning an error, presumably because the command returns a non-zero exit code if there's no process to be killed by that name. I'm concerned that this might be messing up the Node Red flow. I suggest the error handling on that node be disabled, or the exit code `1` be ignored and considered as a success. It might also be good to add the `-w` command-line switch to make the command block until the process is actually killed before moving on with the flow.

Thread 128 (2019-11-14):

Make the Update card check for new audio too

george08, 2019-11-14:
We're in a customer support loop with the Ure Museum at the moment, because they've asked us to update several of the audio tracks they supplied initially. We're happy to update the audio, and have done, but, it sounds from their emails like the new audio has not yet downloaded to the Box.

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

Just noting here that she assumed the Update card updates content (and not the brain software particularly). I think would be better than what we have now - if it could check for both types of updates (content and software).

In the meantime, I guess I'll have to direct them to box.local:1880/prints and have them click the "Check for new audio" button?

Is there anything you'd like me to ask or do to try to help work out why the audio update has apparently not worked?

amcewen, 2019-12-03:
We should (at least to try) not do the automatic updates in the background when we add this, so there's two ways content can be updated: by using the updates card, or clicking on the button in `/prints`.

We should (at least to try out) play the "checking for new content" audio when the button is clicked in `/prints` too.

amcewen, 2019-12-13:
New improved flow and better audio added; the updates card now checks for new content before checking for new software; and we no longer automatically check for new content in the background.

Closed 2019-12-13.

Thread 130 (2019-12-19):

Invent a way to get boxconfig.json on to a new Box at HQ without opening the Box

george08, 2019-12-19:
Because that's fiddly and takes time which would be ideally avoided!

george08, 2019-12-19:
Just hit box.local:1880/prints testing the new 1213 img, and saw this:

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

Wondering if that could be the place for a UI to send the file to the Box, and perhaps even restart it (if that's required).

Could this place also contain the Add Box form? (Or at least a link to /backstage)

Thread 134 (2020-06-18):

Adjust Aux Out volume levels

george08, 2020-06-18:
Yesterday I thought the Aux Out wasn't working because sound only comes out into headphones when the volume is over halfway.

Can we adjust the settings for Aux Out volume so there is sound through headphones even when the volume is low?

amcewen, 2020-06-18:
We can, but it's a hardware fix not a software one.  Already raised as https://github.com/museuminabox/brain-dei-mille/issues/24

Closed 2020-06-18.

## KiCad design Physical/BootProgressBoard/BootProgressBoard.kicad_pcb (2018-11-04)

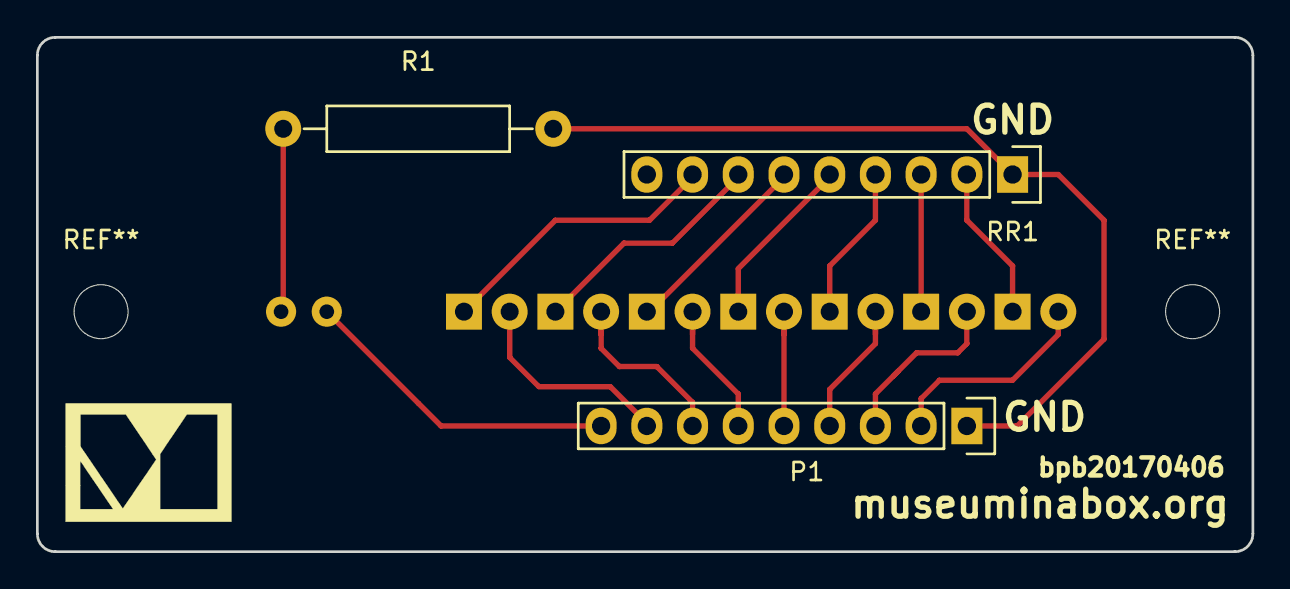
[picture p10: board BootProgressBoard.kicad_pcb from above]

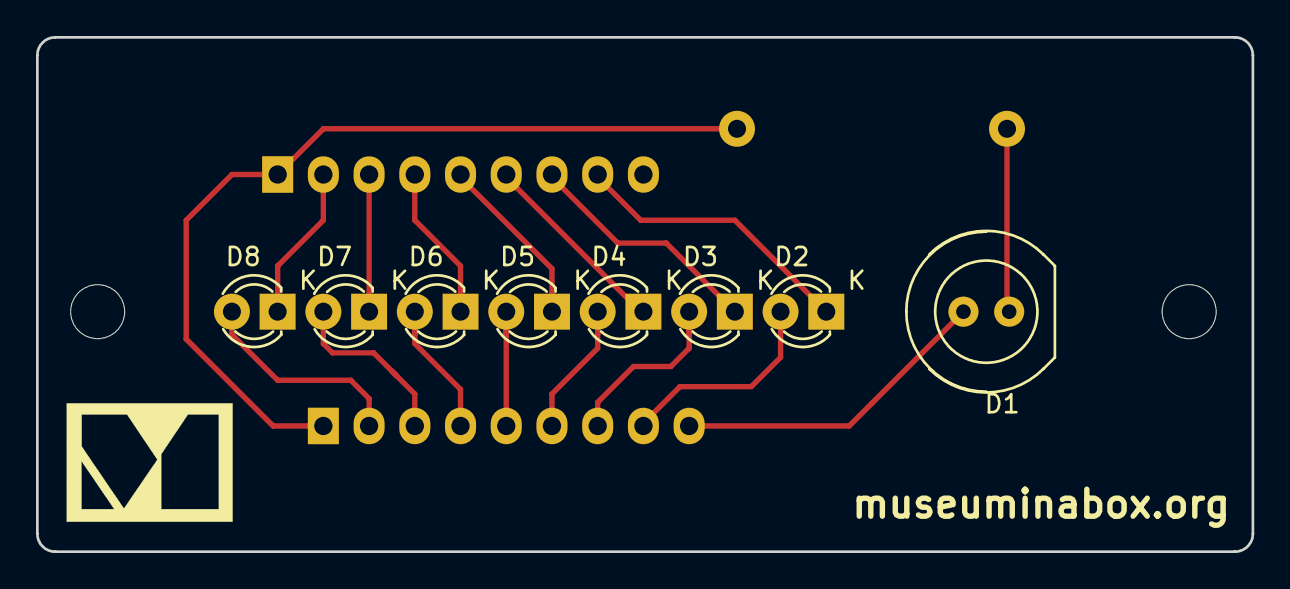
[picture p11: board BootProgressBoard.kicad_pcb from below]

Board: 2 copper layers, 67.5 x 28.6 mm, 11 parts (8 on the bottom side), 17 nets.

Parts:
D1: LED; LED-8MM
D2, D3, D4, D5, D6, D7, D8: LED; LED-3MM
P1: CONN_01X09; Socket_Strip_Straight_1x09
R1: R; Resistor_Horizontal_RM15mm
RR1: RR8; Socket_Strip_Straight_1x09

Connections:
unnamed: D1.1, R1.1
unnamed: D1.2, P1.9
unnamed: D2.1, RR1.8
unnamed: D2.2, P1.8
unnamed: D3.1, RR1.7
unnamed: D3.2, P1.7
unnamed: D4.1, RR1.6
unnamed: D4.2, P1.6
unnamed: D5.1, RR1.5
unnamed: D5.2, P1.5
unnamed: D6.1, RR1.4
unnamed: D6.2, P1.4
unnamed: D7.1, RR1.3
unnamed: D7.2, P1.3
unnamed: D8.1, RR1.2
unnamed: D8.2, P1.2
unnamed: P1.1, R1.2, RR1.1

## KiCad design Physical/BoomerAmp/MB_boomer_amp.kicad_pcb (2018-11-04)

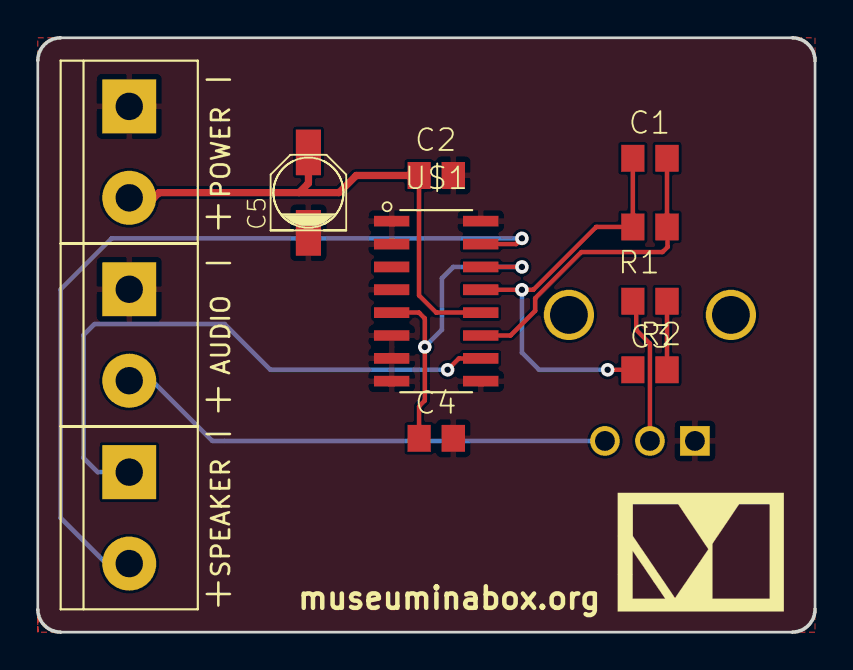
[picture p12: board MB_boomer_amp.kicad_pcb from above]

Board: 2 copper layers, 43.2 x 33.0 mm, 12 parts (0 on the bottom side), 10 nets.

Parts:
AUDIO: GREEN-2P-3.5; TerminalBlock_bornier-2_P5.08mm
C1: 5p; C0805
C2, C4: 100n; C0805
C3: 4.7u; C0805
C5: 10u; PANASONIC_B
POWER: GREEN-2P-3.5; TerminalBlock_bornier-2_P5.08mm
R1: 100k; R0805
R2: 10k; R0805
SPEAKER: GREEN-2P-3.5; TerminalBlock_bornier-2_P5.08mm
U$1: LM4860; SOIC127P600X175-16
VR1: 9MM_SNAP-IN_POT_; 9MM_SNAP-IN_POT

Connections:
/ASIG: AUDIO.2, VR1.3
/VCC: C2.1, C5.+, POWER.2, U$1.12
GND: AUDIO.1, C2.2, C4.2, C5.-, POWER.1, U$1.1, U$1.2, U$1.4, U$1.6, U$1.7, U$1.8, U$1.9, U$1.16, VR1.1
unnamed: C1.1, R1.2, R2.1, U$1.13
unnamed: C1.2, R1.1, U$1.11
unnamed: C3.1, R2.2
unnamed: C3.2, VR1.2
unnamed: C4.1, U$1.5, U$1.14
unnamed: SPEAKER.1, U$1.10
unnamed: SPEAKER.2, U$1.15

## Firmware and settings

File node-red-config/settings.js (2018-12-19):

/**
 * Copyright 2013, 2015 IBM Corp.
 *
 * Licensed under the Apache License, Version 2.0 (the "License");
 * you may not use this file except in compliance with the License.
 * You may obtain a copy of the License at
 *
 * http://www.apache.org/licenses/LICENSE-2.0
 *
 * Unless required by applicable law or agreed to in writing, software
 * distributed under the License is distributed on an "AS IS" BASIS,
 * WITHOUT WARRANTIES OR CONDITIONS OF ANY KIND, either express or implied.
 * See the License for the specific language governing permissions and
 * limitations under the License.
 **/

// The `https` setting requires the `fs` module. Uncomment the following
// to make it available:
//var fs = require("fs");

module.exports = {
    // the tcp port that the Node-RED web server is listening on
    uiPort: 1880,

    editorTheme: { menu: { "menu-item-help": {
        label: "Node-RED Pi Website",
        url: "http://nodered.org/docs/hardware/raspberrypi.html"
    } } },


    // By default, the Node-RED UI accepts connections on all IPv4 interfaces.
    // The following property can be used to listen on a specific interface. For
    // example, the following would only allow connections from the local machine.
    //uiHost: "127.0.0.1",

    // Retry time in milliseconds for MQTT connections
    mqttReconnectTime: 15000,

    // Retry time in milliseconds for Serial port connections
    serialReconnectTime: 15000,

    // Retry time in milliseconds for TCP socket connections
    //socketReconnectTime: 10000,

    // Timeout in milliseconds for TCP server socket connections
    //  defaults to no timeout
    //socketTimeout: 120000,

    // Timeout in milliseconds for HTTP request connections
    //  defaults to 120 seconds
    //httpRequestTimeout: 120000,

    // The maximum length, in characters, of any message sent to the debug sidebar tab
    debugMaxLength: 1000,

    // The file containing the flows. If not set, it defaults to flows_<hostname>.json
    flowFile:'flows_brain.json',

    // To enabled pretty-printing of the flow within the flow file, set the following
    //  property to true:
    flowFilePretty: true,

    // By default, all user data is stored in the Node-RED install directory. To
    // use a different location, the following property can be used
    userDir: '/root/.node-red/',

    // Node-RED scans the `nodes` directory in the install directory to find nodes.
    // The following property can be used to specify an additional directory to scan.
    //nodesDir: '/home/nol/.node-red/nodes',

    // By default, the Node-RED UI is available at http://localhost:1880/
    // The following property can be used to specifiy a different root path.
    // If set to false, this is disabled.
    httpAdminRoot: '/admin',

    // Some nodes, such as HTTP In, can be used to listen for incoming http requests.
    // By default, these are served relative to '/'. The following property
    // can be used to specifiy a different root path. If set to false, this is
    // disabled.
    //httpNodeRoot: '/red-nodes',

    // The following property can be used in place of 'httpAdminRoot' and 'httpNodeRoot',
    // to apply the same root to both parts.
    //httpRoot: '/red',

    // When httpAdminRoot is used to move the UI to a different root path, the
    // following property can be used to identify a directory of static content
    // that should be served at http://localhost:1880/.
    httpStatic: '/home/pi/miab/web-static/',

    // Securing Node-RED
    // -----------------
    // To password protect the Node-RED editor and admin API, the following
    // property can be used. See http://nodered.org/docs/security.html for details.
    //adminAuth: {
    //    type: "credentials",
    //    users: [{
    //        username: "admin",
    //        password: "$2a$08$zZWtXTja0fB1pzD4sHCMyOCMYz2Z6dNbM6tl8sJogENOMcxWV9DN.",
    //        permissions: "*"
    //    }]
    //},

    // To password protect the node-defined HTTP endpoints (httpNodeRoot), or
    // the static content (httpStatic), the following properties can be used.
    // The pass field is a bcrypt hash of the password.
    // See http://nodered.org/docs/security.html#generating-the-password-hash
    //httpNodeAuth: {user:"user",pass:"$2a$08$zZWtXTja0fB1pzD4sHCMyOCMYz2Z6dNbM6tl8sJogENOMcxWV9DN."},
    //httpStaticAuth: {user:"user",pass:"$2a$08$zZWtXTja0fB1pzD4sHCMyOCMYz2Z6dNbM6tl8sJogENOMcxWV9DN."},

    // The following property can be used to enable HTTPS
    // See http://nodejs.org/api/https.html#https_https_createserver_options_requestlistener
    // for details on its contents.
    // See the comment at the top of this file on how to load the `fs` module used by
    // this setting.
    //
    //https: {
    //    key: fs.readFileSync('privatekey.pem'),
    //    cert: fs.readFileSync('certificate.pem')
    //},

    // The following property can be used to disable the editor. The admin API
    // is not affected by this option. To disable both the editor and the admin
    // API, use either the httpRoot or httpAdminRoot properties
    //disableEditor: false,

    // The following property can be used to configure cross-origin resource sharing
    // in the HTTP nodes.
    // See https://github.com/troygoode/node-cors#configuration-options for
    // details on its contents. The following is a basic permissive set of options:
    //httpNodeCors: {
    //    origin: "*",
    //    methods: "GET,PUT,POST,DELETE"
    //},

    // If you need to set an http proxy please set an environment variable
    // called http_proxy (or HTTP_PROXY) outside of Node-RED in the operating system.
    // For example - http_proxy=http://myproxy.com:8080
    // (Setting it here will have no effect)
    // You may also specify no_proxy (or NO_PROXY) to supply a comma separated
    // list of domains to not proxy, eg - no_proxy=.acme.co,.acme.co.uk

    // The following property can be used to add a custom middleware function
    // in front of all http in nodes. This allows custom authentication to be
    // applied to all http in nodes, or any other sort of common request processing.
    //httpNodeMiddleware: function(req,res,next) {
    //   // Handle/reject the request, or pass it on to the http in node
    //   // by calling next();
    //   next();
    //},

    // Anything in this hash is globally available to all functions.
    // It is accessed as context.global.
    // eg:
    //    functionGlobalContext: { os:require('os') }
    // can be accessed in a function block as:
    //    context.global.os

    functionGlobalContext: {
        // os:require('os'),
        // octalbonescript:require('octalbonescript'),
        // jfive:require("johnny-five"),
        // j5board:require("johnny-five").Board({repl:false})
    },
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

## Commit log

2015-12-01 Add Node RED flow for the video brain.
2015-12-01 Add Node RED flow for the audio brain.
2015-12-07 Add laser-cutting file for standalone RFID reader cover.
2015-12-07 Add laser-cutting file for self-contained MiaB.
2015-12-07 Log Boops to local CSV and web (for video boxes)
    [boops_log.csv]
2016-04-02 Make brain setup easier. Most of issue #17.
    Merge audio and video flows together - chooses behaviour at run time based on context.global.box_settings.brain_type
    Load settings (from /home/pi/miab/box-config.json) on startup and store them in context.global.box_settings
    Add a web UI '/setup' which downloads a list of boxes from www.museuminabox.org and gives you a simple drop-down menu to choose which box this brain is inside
    Add a web UI '/prints' (which you get redirected to from a successful submission on '/setup') which lists prints for this box and provides a 'Write tag' button next to each
    Add code to write print's NFC tag content to a tag when the 'Write tag' button is clicked
2016-04-11 Added more detailed instructions for WiFi 📡
2016-05-12 Update for battery & volume control version of the brain.
2016-05-25 Added some labels and explanation to the case design
2016-06-08 Add frog case design.
2016-08-23 Fix a couple of bugs in the ansible script.
    Bits missed during development as I'd obviously installed things and/or run Node RED before working out which files were needed. Running through the process from a bare SD card showed up a few bits that needed tweaking.
    [settings.js]
2016-09-06 Switch back to wpa_supplicant.conf (from wicd-curses) for WiFi management
2016-09-06 Switch to herokuapp domain, and other tweaks.
2016-09-08 Finished provisioning work.
    * /setup now correctly downloads all the content when run, rather than needing to wait for next boot (was passing through parts of old web requests to the "download list of box contents" request, which confused the Rails app)
    * Hostname is set to brain
2016-09-22 Switch to sox for audio playback (copes with different sample rates)
2016-09-27 Add Kicad files for boot progress PCB
    [BootProgressBoard.kicad_pcb, BootProgressBoard.sch]
2016-09-28 Update case to micro-USB power, using Boot Progress Board PCB
2016-09-28 Add spacer to make the LEDs line up better above the PCB
2016-11-07 Change user the boot progress script runs as, so the LEDs light up again.
2016-12-06 Add wiring instructions
2016-12-13 Add support for the Adafruit DAC & volume buttons
2017-03-27 Tweaks for RPi3 timings for the LEDs. Fixes #25
2017-04-11 Drop www. from URL, move logo & URL
    [BootProgressBoard.kicad_pcb]
2017-09-13 Latest version
    [BootProgressBoard.kicad_pcb]
2017-09-13 Add assembly instructions
2018-02-14 Use a special RFID tag to launch wifi configuring.
    Also fixed bug so it plays the right message when the WiFi config script starts.
    And add ability to write the config tags to http://brain.local:1880/prints
2018-02-24 Remove support for video playback. Fixes #44
    [settings.js]
2018-03-07 Record boop ends as well as boop starts. UNTESTED. Part of #40
    Need the corresponding part in the Heart app to be implemented before we can test this.
    [boops_log.csv]
2018-03-13 Rework wiring loom for simpler assembly. Fixes #57
    [WiringLoom.fzz]
2018-03-15 Fix List of Prints response
2018-03-21 Updates to build instructions following the latest round of manufacturing
    [WiringLoom.fzz]
2018-04-14 Improve display of `/prints` screen. Part of #73
2018-04-14 Add simple upgrade process. First pass at #55.
    Also fixed print image display on `/prints`, part of #73
2018-10-22 Initial version of the amp PCB. Part of #86
    [MB_boomer_amp.brd, MB_boomer_amp.sch]
2018-10-22 Amp PCB converted to Kicad to match BootProgressBoard. Screw terminals switched to 5.08mm pitch. Part of #86
    [MB_boomer_amp.brd, MB_boomer_amp.kicad_pcb, MB_boomer_amp.sch]
2018-11-04 Add logo to the Boomer amp. Part of #86
    [BootProgressBoard.kicad_pcb, MB_boomer_amp.kicad_pcb]
2018-11-04 Ignore Kicad backup files
2018-11-19 Checking in two skull v1.2 files
    Changes include:
    - resolved double line issue with shim and t-nut holes
    - ID number now has three digit shapes
    - Update to accommodate the new reader
    - Holes enlarged to accommodate M4 bolts
    - Base frame shape adjusted to accommodate new t-nuts
2018-12-02 Jig to make it easier to glue the SL030 RFID reader in the right place
    [rfid_positioning_jig.dxf]
2018-12-02 Update jig for new MFRC522 RFID reader
    [rfid_positioning_jig.dxf]
2018-12-04 New wiring loom for the new SPI-based RFID reader
    [WiringLoom.fzz]
2018-12-11 Modified colour for Pimironi order
    Added green for a kiss cut
2018-12-11 v1.2 files for ply and acrylic for
    New skull files in acrylic and ply from Paul at Pimironi, used to cut
    the batch of 80 boxes in November.
2018-12-11 Acrylic reader spacers
    3mm clear acrylic replacement reader spacers for flipped readers in 18x
    transparent boxes
    [skull_20_reader_spacers.dxf]
2018-12-11 Skull reader spacers update
    Update to line colours and weighting for quotes from local cutters
    [skull_20_reader_spacers.dxf]
2018-12-17 Added "check for content" button to `/prints`. Fixes #100
2018-12-18 Update build script and flow for new RC522 RFID reader. Part of #92
2018-12-18 Add Gillian object to all collections (hard-coded in /prints). Fixes #68
2018-12-18 Group prints on `/prints` by collection. Most of #101
2018-12-19 Fix a couple of bugs having moved /admin. Part of #68
2018-12-19 Change port back to 1880 to prevent problems with the WiFi config. Part of #83
    [settings.js]
2018-12-19 Update brain web UI with changes from @george08. Fixes #83 and #101
    [settings.js]
2018-12-23 Switch GPIO pin for one of the yellow LEDs. Fixes #104
2018-12-23 Update instructions for the new wiring loom. Part of #104
    [WiringLoom.fzz]
2019-01-16 Use correct *print* ID for the Gillian totems. Fixes #68
2019-09-09 Add support for an RTC. Part of https://github.com/museuminabox/brain-dei-mille/issues/1
2019-10-21 Seemed to need a marker to make Ansible *actually* apply the RTC changes. Final part of https://github.com/museuminabox/brain-dei-mille/issues/1
